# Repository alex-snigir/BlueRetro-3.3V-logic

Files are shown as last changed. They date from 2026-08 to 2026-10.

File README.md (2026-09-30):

*Read this in other languages: [English](README_EN.md)*

# BlueRetro + Murmulator: Bluetooth-джойстики для эмулятора ретро компьютеров на перфборде

Подключение Bluetooth-геймпадов (Xbox One, PS/Switch и других HID-устройств) к эмулятору ретро компьютеров [Murmulator](https://murmulator.ru/howto) (RP2040) в качестве двух NES/Dendy-совместимых джойстиков через самодельный адаптер [BlueRetro](https://github.com/darthcloud/BlueRetro) (ESP32), выступающий мостом.

BlueRetro эмулирует на выходе стандартный протокол сдвигового регистра NES/Dendy (CLOCK/LATCH/DATA) и подключается напрямую к джойстик-портам DE-9 Мурмулятора — проводные NES-контроллеры в проекте не используются.

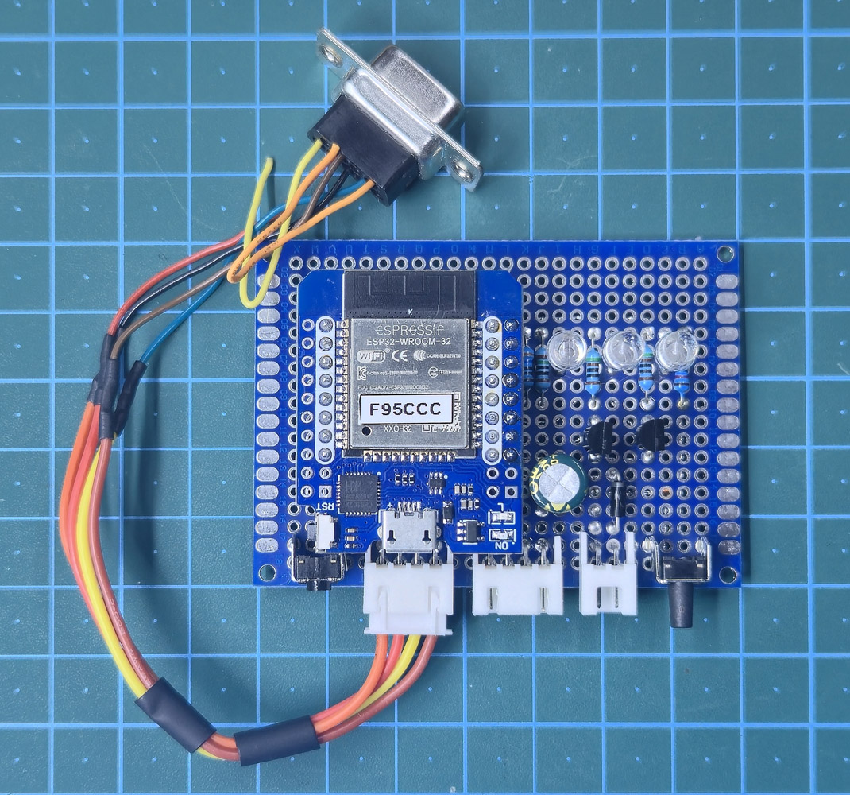
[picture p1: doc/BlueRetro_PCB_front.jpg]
BlueRetro PCB


## Железо

- **Хост:** Murmulator (RP2040, сборка на перфборде) — VGA, PS/2-клавиатура, аудио, джойстик-порты.
- **Адаптер:** самодельный BlueRetro на ESP32 D1 mini (MH-ET LIVE, CH9102), прошивка по спецификации HW1, собственная KiCad-схема с глобальным и портовыми светодиодами статуса, входной защитой питания и вынесенной кнопкой BOOT/IO0.
- **Кабели:** JST XH 4-pin (BlueRetro) → DE-9 (Murmulator), распиновка и разводка описаны в project summary.
- **Схемы:** KiCad-проект платы BlueRetro — [`schematics/BlueRetro3V3/`](schematics/BlueRetro3V3/) (готовый PDF: [`BlueRetro3V3.pdf`](schematics/BlueRetro3V3/BlueRetro3V3.pdf)).

## Документация

| Файл | Описание |
|---|---|
| [`doc/blueretro-murmulator-project-summary.md`](doc/blueretro-murmulator-project-summary.md) / [`_EN`](doc/blueretro-murmulator-project-summary_EN.md) | Полное техническое описание: выбор платы, распиновка, питание, LED-индикация, прошивка, проверка осциллографом |
| [`doc/blueretro-murmulator-user-guide.md`](doc/blueretro-murmulator-user-guide.md) / [`_EN`](doc/blueretro-murmulator-user-guide_EN.md) | Повседневное использование: пейринг и отключение Bluetooth-геймпадов |
| [`doc/blueretro-xbox-one-nes-oscillograms.pdf`](doc/blueretro-xbox-one-nes-oscillograms.pdf) / [`_EN`](doc/blueretro-xbox-one-nes-oscillograms_EN.pdf) | Осциллограммы проверки: геймпад Xbox One как NES-джойстик — LATCH, «ничего не нажато» и поочерёдное нажатие всех 8 кнопок (исходники: [`.docx`](doc/blueretro-xbox-one-nes-oscillograms.docx) / [`_EN.docx`](doc/blueretro-xbox-one-nes-oscillograms_EN.docx); снимки — [`doc/XBox One as NES Joystick Debugging/`](<doc/XBox One as NES Joystick Debugging/>)) |
| [`murmulator-vga-project-summary.md`](https://github.com/alex-snigir/Murmulator-RP2040-Black-Perfboard-VGA/blob/master/doc/murmulator-vga-project-summary.md) / [`_EN`](https://github.com/alex-snigir/Murmulator-RP2040-Black-Perfboard-VGA/blob/master/doc/murmulator-vga-project-summary_EN.md) | Базовая сборка Мурмулятора на перфборде (хост-платформа) — отдельный репозиторий |

## Статус

Железо собрано и проверено: пейринг, работа двух портов и протокол CLOCK/LATCH/DATA подтверждены осциллографом на реальных нажатиях кнопок Xbox One.

## Благодарности

Проект основан на [BlueRetro](https://github.com/darthcloud/BlueRetro) авторства darthcloud (CERN-OHL-P-2.0 / Apache-2.0) и платформе [Murmulator](https://murmulator.ru/howto).

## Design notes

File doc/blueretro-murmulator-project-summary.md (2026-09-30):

# Project Summary: BlueRetro — подключение 2х NES/Dendy джойстиков к Murmulator

**Версия документа:** 1.0 · **Дата:** 2026-09-30

## Связанные документы
- **Базовый проект**: [BlueRetro](https://github.com/darthcloud/BlueRetro) (darthcloud) — open-source адаптер Bluetooth-контроллеров для ретро-консолей на базе ESP32, на чьих прошивке и HW1-спецификации построена данная сборка. Документация: [BlueRetro Wiki](https://github.com/darthcloud/BlueRetro/wiki).
- **Связанный проект-хост**: `murmulator-vga-project-summary.md` (проект "Murmulator") — одна из сборок Мурмулятора (RP2040 Black Perfboard: VGA, Joystick, AudioOut, AudioIn), используемая для текущей интеграции BlueRetro; не единственная возможная целевая платформа.

## Цель проекта
Подключить Bluetooth-геймпады (Xbox One, PS/Switch и др. HID-устройства) к Murmulator (устройство на базе RP2040) в качестве двух NES/Dendy-совместимых джойстиков через устройство BlueRetro, которое эмулирует стандартный протокол сдвигового регистра NES/Dendy (9-pin, CLOCK/LATCH/DATA) на выходе, выступая мостом между Bluetooth-контроллерами и Мурмулятором. Физические проводные NES/Dendy-джойстики в проекте не используются.

## Контекст компонентов

### Murmulator (эмулятор ретро компьютеров)
- Основа: RP2040 black clone, самодельная плата (Perfboard).
- Функциональность (согласно `murmulator-vga-project-summary.md`): вывод VGA, поддержка джойстика, аудиовыход, аудиовход.
- Данный проект расширяет базовую платформу поддержкой двух NES/Dendy джойстиков через BlueRetro.

### BlueRetro (адаптер)
- Открытое железо и прошивка на базе ESP32, лицензии CERN-OHL-P-2.0 (hardware) и Apache-2.0 (software).
- Изначально спроектирован как переходник "Bluetooth-контроллер → консоль": поддерживает Wii, Switch, PS3, PS4, PS5, Xbox One, Xbox Series X|S и generic HID Bluetooth (BR/EDR и LE) устройства, а на выходе эмулирует протоколы множества консолей, включая NES.
- Для NES/Famicom: может эмулировать стандартный 8-кнопочный NES-контроллер (GamePad), мультитап Four Score на 4 контроллера (Dual), японский 4P-адаптер (Alt), клавиатуру Famicom или Hori Trackball (мышь).
- В данном проекте используется **штатный** сценарий работы BlueRetro: адаптер физически подключается к джойстик-порту хоста (в данном случае — к Murmulator) и эмулирует на выходе стандартный NES/Dendy-протокол сдвигового регистра, а на вход принимает Bluetooth/HID-геймпады (Xbox One и др.). Проводные NES/Dendy-джойстики на входе BlueRetro не используются.
- Схемы распайки NES-кабелей и особенности PAL-подтяжек описаны в [BlueRetro Cables Build Instructions](https://github.com/darthcloud/BlueRetro/wiki/BlueRetro-Cables-Build-Instructions): для PAL-систем требуется добавление подтягивающих резисторов 3.6К к NES 5V (pin 5) на пады IO18, IO5 и IO32.
- Общая сборка описана в [BlueRetro DIY Build Instructions](https://github.com/darthcloud/BlueRetro/wiki/BlueRetro-DIY-Build-Instructions): прошивка BlueRetro на ESP32, сборка кабеля-адаптера под целевую систему, опциональная настройка через Web Bluetooth.
- **В данном проекте**: на плате BlueRetro распаяны 2 разъёма JST XH 1x04 (J1/J2), к которым подключены самодельные кабели-переходники JST XH 4-pin male → DE-9 female, оканчивающиеся разъёмами DE-9 female — они подключаются напрямую к джойстик-портам DE-9 male на Murmulator.
- Настройка выполняется через BLE Web Config (Desktop/Android Chrome), позволяющий гибко маппить кнопки, настраивать turbo-режимы и т.д.

## Выбор Dev Board (ESP32)

**Итоговое решение: ESP32 D1 mini MH-ET LIVE (CH9102).**

**Рассмотренные альтернативы:**

| Плата | Вердикт |
|---|---|
| ESP32-WROOM-32 DevKit, **30 pin**, CP2102 | Отпала — на этом форм-факторе физически **не выведен пин GPIO0**, необходимый для BOOT/pairing и всех режимов сброса BlueRetro (проверено по пинаутам конкретных плат в наличии) |
| ESP32-WROOM-32 DevKit, **38 pin**, CP2102 | Технически пригодна и соответствует официальной рекомендации автора BlueRetro (см. ниже) — GPIO0 выведен. Не выбрана, так как потребовала бы переделки уже готовой и проверенной в железе KiCad-схемы (другой footprint, другие габариты платы); на текущем этапе (PCB близка к финализации) это признано нецелесообразным |
| ESP32 D1 mini MH-ET LIVE, CH9102 (выбрана) | Схема и распиновка уже спроектированы и проверены в железе под эту плату; конфликтов бортовой периферии с используемыми пинами (IO2, IO4, IO5, IO17, IO18, IO19, IO22, IO32, IO0) не выявлено |

**On-board LED платы:** на ESP32 D1 mini MH-ET LIVE штатный (built-in) LED подключён к **GPIO2** и загорается, когда GPIO2 находится в состоянии **HIGH**. В данной сборке GPIO2 занят под индикацию порта 1 (см. раздел «LED-подсистема индикации» ниже) — при HIGH на IO2 (LED порта 1 через MOSFET Q1 горит) штатный on-board LED платы будет параллельно повторять это состояние (гореть одновременно с внешним LED порта 1). Это не создаёт электрического конфликта (GPIO2 остаётся выходом, on-board LED — лишь дополнительная, немного избыточная индикация того же сигнала), но стоит иметь в виду при сборке в корпусе — штатный LED платы может быть виден снаружи, если не закрыт.

**Официальная позиция сообщества BlueRetro:** автор проекта (darthcloud) в официальной документации указывает конкретную рекомендуемую плату — **ESP32-DevKitC-32E/D с модулем ESP-WROOM-32** (38-pin форм-фактор). Причины:
- На дешёвых клонах бывают конфликты бортовой периферии с пинами, которые использует BlueRetro (задокументированный случай — светодиод на IO5 на плате Wemos Lolin32, из-за которого прошивка зависает в цикле сброса).
- Важно, чтобы внутри стоял модуль именно **WROOM** (не WROVER) — у WROVER на 2 GPIO меньше из-за встроенной PSRAM.
- Сторонние производители готовых китов для BlueRetro (например, RetroRosetta) придерживаются той же рекомендации — использовать только официальные DevKit-платы.

**Почему аргумент «штатная кнопка BOOT» не сыграл роли:** кнопки BOOT и RESET в данном проекте в любом случае выносятся на корпус устройства (3D-печатной коробки) отдельными проводами — поэтому наличие или отсутствие штатной кнопки BOOT на самой плате не имеет значения при выборе.

**Известный компромисс выбранной платы — нагрев регулятора:** встроенный линейный стабилизатор **AMS1117** (5V→3.3V) на D1 mini греется в работе до ~54°C. Это не уникальная проблема D1 mini — тот же AMS1117 стоит и на WROOM-32 DevKit платах, но на маленькой плате D1 mini меньше меди PCB для отвода тепла. 54°C не критично для самого регулятора, но близко к температуре размягчения PLA (используется в 3D-печатном корпусе) — при плотной компоновке возможна деформация пластика при долгой работе без вентиляции.

**Риск принят** — сборка эксплуатируется как есть. Если нагрев всё же станет проблемой, возможны два варианта:
1. Вентиляционное отверстие в корпусе над регулятором.
2. Обход/выпайка встроенного AMS1117 с подачей готовых 3.3V от отдельного внешнего DC-DC регулятора (по аналогии с доработкой SD-модуля в `murmulator-vga-project-summary.md`, раздел 2).

## Аппаратная сборка BlueRetro
- Используется DIY-сборка на базе **ESP32 D1 mini (MH-ET LIVE, USB-serial чип CH9102)** — самодельная, не готовая плата BlueRetroHW.
- **⚠️ Кнопка BOOT/IO0 отсутствует на плате D1 mini.** В отличие от полноразмерного ESP32 DevKitC, на D1 mini физически разведена только кнопка **RST/EN** (сброс модуля) — отдельной кнопки BOOT нет. Функции BlueRetro (пейринг, сброс конфигурации, factory reset — см. раздел "Кнопка BOOT (IO0)" ниже) завязаны именно на IO0, поэтому нужно **допаять отдельную кнопку между IO0 и GND**.
  - Внешний pull-up резистор в теории не обязателен — ESP32 включает внутренний pull-up на IO0 (strapping-пин) аппаратно при старте. Кнопка просто замыкает IO0 на GND при нажатии.
  - **На практике встроенный pull-up на конкретном модуле оказался нестабильным**, поэтому в финальной KiCad-схеме внешний резистор **R1 = 10 кОм (от IO0 к +3.3V) впаян безусловно**, как штатный компонент, а не как опциональный запасной вариант.

### Кнопка BOOT (IO0) — функции BlueRetro
⚠️ Тайминги и действия ниже соответствуют используемой версии прошивки (`v25.04_hw1`, см. раздел "Прошивка firmware"). В других версиях BlueRetro длительности удержания и результат могут отличаться — сверяться с BlueRetro Wiki для конкретной установленной версии.
- Короткое нажатие (< 3 сек) — обычный сброс системы.
- Удержание 3–6 сек (LED IO17 мигает медленно) — запуск режима пейринга (pairing mode).
- Удержание 6–10 сек (LED IO17 мигает быстро) — сброс к дефолтной конфигурации.
- Удержание > 30 сек — полный factory reset ESP32 (заводская прошивка + сброс настроек).
- В режиме пейринга короткое нажатие останавливает пейринг / отключает все Bluetooth-устройства.

## Распиновка (согласовано с murmulator-vga-project-summary.md)

**Топология:** ESP32 (BlueRetro) → разъёмы J1/J2 (JST XH 1x04, на плате BlueRetro) → кабель-переходник (JST XH 4-pin male → DE-9 female) → разъёмы J6/J7 (DE-9 male, на плате Murmulator) → GPIO Pico.

| Сигнал | Нога ESP32 (BlueRetro) | JST XH J1 (P1) | JST XH J2 (P2) | DE-9 Murmulator J6 (P1) | DE-9 Murmulator J7 (P2) | GPIO Pico |
|---|---|---|---|---|---|---|
| LATCH (общий) | IO32 | pin 1 | pin 1 | pin 3 | pin 3 | GP15 |
| CLOCK порт 1 | IO5 | pin 2 | — | pin 4 | — | GP14 |
| CLOCK порт 2 | IO18 | — | pin 2 | — | pin 4 | GP14* |
| DATA порт 1 | IO19 | pin 3 | — | pin 2 | — | GP16 |
| DATA порт 2 | IO22 | — | pin 3 | — | pin 2 | GP17 |
| GND | GND ESP32 | pin 4 | pin 4 | pin 8 | pin 8 | GND |
| VCC (+5V) | — | не разведено | не разведено | pin 6 | pin 6 | **не подключать** |

**Распайка кабеля-переходника (JST XH 4-pin male → DE-9 female), одинаковая для обоих портов:**

| JST XH pin | Сигнал | DE-9 pin |
|---|---|---|
| 1 | LATCH | 3 |
| 2 | CLOCK | 4 |
| 3 | DATA | 2 |
| 4 | GND | 8 |

\* **CLOCK и LATCH генерирует RP2040 (Murmulator выступает хостом/консолью)** — это один физический сигнал GP14/GP15, разведённый на оба разъёма J6 и J7 одновременно. IO5 и IO18 на ESP32 (BlueRetro эмулирует джойстик/слейв) — это два **входа**, слушающие этот сигнал, а не два независимых генератора. Электрического конфликта (bus contention) при объединении не возникает, так как RP2040 — единственный активный драйвер линии. Прошивка BlueRetro внутренне обрабатывает IO5/IO18 как два независимых входа CLOCK (на случай консолей, где CLOCK P1/P2 физически не объединены) — при подключении к Murmulator оба входа неизбежно получают один и тот же физический сигнал.

VCC (pin 6, DE-9 Murmulator) сознательно не подключается: ESP32 внутри BlueRetro работает на 3.3V-логике, сигнальные линии заводятся на GPIO Pico напрямую без level-shifter'ов; питание BlueRetro организовано отдельно, через собственный разъём J3 платы (см. раздел "Питание BlueRetro"). На разъёмах JST XH J1/J2 (порты джойстика на стороне BlueRetro) линии +5V нет вообще — там только 4 сигнала (LATCH/CLOCK/DATA/GND).

## Питание BlueRetro (ESP32-модуль)
- ESP32 D1 mini (со встроенным стабилизатором AMS1117, 5V→3.3V) может питаться двумя способами — по отдельности или одновременно:
  1. **Через J3 платы BlueRetro** — от разъёма J2 Мурмулятора (отвод «сырого» +5V внешнего PSU, до диода D1 Мурмулятора, см. `murmulator-vga-project-summary.md`, раздел 10) → диод Шоттки D1 = 1N5819 на плате BlueRetro → пин 5V D1 mini. Из-за падения на диоде на пин 5V D1 mini приходит не 5V, а меньше (~4.5–4.7V).
  2. **Через micro-USB на D1 mini** (от ПК или USB-адаптера).
- **Одновременное подключение J3 и micro-USB допустимо.** На D1 mini защитного диода нет: пин 5V напрямую соединён с VBUS micro-USB и входом стабилизатора 3.3V. Развязку обеспечивает только диод Шоттки D1 = 1N5819 на входе J3: он не пропускает ток от USB в PSU Мурмулятора, а напряжение после него ниже 5V, поэтому при одновременном подключении нагрузку берёт на себя USB. Условие безопасности — напряжение PSU минус падение на D1 (при малом токе ~0.15–0.25V) должно оставаться ниже напряжения USB-порта; иначе PSU будет подпитывать VBUS компьютера обратным током. При PSU ~5.0V условие выполняется с запасом.
- **⚠️ Ограничение при питании только через J3:** BlueRetro и оба джойстика работают только при подключённом внешнем PSU Мурмулятора. На YD-RP2040 нет доступного USB VBUS до объединяющего диода BAT54C, поэтому от USB Мурмулятора BlueRetro не запитать. При питании через micro-USB D1 mini это ограничение не действует.
- **Измерено (мультиметр):** пиковое потребление тока ESP32 по шине 5V при активном BT-радио — **~155 мА**. Питание через J2 (на плате Мурмулятора) → J3 (на плате BlueRetro) идёт в обход диода BAT54C и узла Vout Мурмулятора (см. `murmulator-vga-project-summary.md`), поэтому эта нагрузка не делит бюджет тока с PS/2-клавиатурой и не ограничена номиналом BAT54C (~150–300 мА на плечо) — запас по току достаточен.
- GND сигнальных линий (LATCH/CLOCK/DATA) общий с Мурмулятором при любом варианте питания — через разъёмы J1/J2 (JST XH) и кабели-переходники к J6/J7.

## Входная защита питания, RESET и развязка

**Разъём внешнего 5V (J3) и защитный диод D1:**
- **J3** — отдельный 2-контактный разъём («External 5V Power Connector»), через который на плату заводится питание от шины 5V внешнего PSU (см. раздел «Питание BlueRetro» выше).
- **D1 = 1N5819** (Schottky, 40V/1A) включён между J3 и шиной +5V: анод — со стороны J3, катод — со стороны +5V. Функция — защита от переполюсовки / развязка входа (аналог diode-OR BAT54C на самом Мурмуляторе, см. `murmulator-vga-project-summary.md`, раздел 10).

**Кнопка RESET (SW2):**
- Отдельная кнопка **SW2**, замыкающая **RST** ESP32-модуля на GND — штатный аппаратный сброс модуля, независимый от логики BOOT/IO0 (см. таблицу функций кнопки BOOT выше).

**Развязывающие конденсаторы (bulk + bypass на обеих шинах питания):**

| Шина | Bulk (электролит) | Bypass (керамика) |
|---|---|---|
| +5V (вход, после J3/D1) | C5 = 470 мкФ | C6 = 100 нФ |
| +3V3 (выход стабилизатора ESP32-модуля) | C8 = 220 мкФ | C7 = 100 нФ |

Оба конденсатора на каждой шине включены параллельно, между шиной и GND — классическая пара «объёмная фильтрация + высокочастотная развязка».

---

## LED-подсистема индикации (финальная, проверено в железе)

По документации BlueRetro Wiki (разделы про LED usage) индикация состоит из двух типов светодиодов: **один global-status LED на IO17** и до **четырёх port-status LED** (по одному на порт). В данной сборке реализованы global-LED + два port-LED (на оба порта джойстика, P1/P2).

**Примечание про IO17 vs встроенный LED платы:** на некоторых ESP32 DevKitC/D1 mini платах штатный (built-in) LED сидит на IO2, но в прошивке BlueRetro этот вывод занят под цепь авто-программирования — поэтому для индикации нужен отдельный внешний светодиод именно на IO17, не полагаясь на встроенный power/status LED платы.

**Распределение выводов ESP32:**

| ESP32 IO | Функция | LED | Способ подключения |
|---|---|---|---|
| IO17 | Global status (статус адаптера / ошибка / пейринг) | D3, синий | двухрезисторная pull-up схема (прямо) |
| IO2 | Port 1 status | D4, зелёный | через MOSFET Q1 (2N7000) |
| IO4 | Port 2 status | D5, зелёный | через MOSFET Q2 (2N7000) |

IO2/IO4/IO17 — все strapping-пины ESP32. Через MOSFET заведены только port-LED D4 (IO2) и D5 (IO4) — требование данной аппаратной ревизии BlueRetro, чтобы нагрузка LED не мешала загрузке; IO17 (D3) использует отдельную pull-up-схему без MOSFET (см. выше). Порты 3/4 (при расширении) — это IO12/IO15, но в режиме PlayStation они переназначаются под индикацию аналогового режима; для NES-режима неактуально.

**Логика поведения (подтверждена реальным тестом):**
- Питание, без ошибки → авто-пейринг: global-LED (IO17) **пульсирует** + LED первого доступного порта (IO2) **пульсирует**; второй порт (IO4) выключен.
- 1-й геймпад подключён → IO17 гаснет, порт 1 (IO2) **solid**.
- 2-й геймпад подключён → порт 2 (IO4) **solid**, IO17 остаётся выключенным.
- Отключение геймпада → его port-LED гаснет; при освобождении порта адаптер возвращается в пейринг (global + первый свободный порт снова пульсируют).

### Схема global-status LED IO17 (двухрезисторный вариант)

⚠️ Отличается от официальной однорезисторной схемы вики (R36 ≈ 65 Ом–1 кОм, LED прямо между узлом и GND). В данной сборке — **два резистора**, что улучшает поведение:

```
+3V3 --[R2 360R]--+-- IO17 (U1 pin 25)
                  |
                  +--[R3 150R]--[D3 anode >|< cathode]-- GND
```
IO17 подключён к узлу между R2 и R3 (со стороны анода LED), а не к GND-стороне.

**Роли резисторов:**
- **R2 = 360R** — pull-up 3.3V→IO17. Обеспечивает fail-safe (при high-Z LED тускло горит) и определяет паразитный сток в GPIO при LOW. На рабочую яркость **не влияет**.
- **R3 = 150R** — последовательный токоограничивающий резистор LED. Задаёт яркость в HIGH-PWM (пульсация/solid). Ограничивает ток при активном push-pull HIGH.

**Логика (fail-safe по умолчанию):**
- IO17 по умолчанию (не сконфигурирован, high-Z/вход) → R2 дотягивает узел к 3.3V → **LED тускло горит сам по себе**, без команды прошивки.
- Прошивка после успешного старта **явно переводит IO17 в выход LOW** → узел к 0V → **LED гаснет**.
- Смысл инверсии: если прошивка не загрузилась (краш до инициализации) — IO17 остаётся high-Z, LED **продолжает гореть** = индикация ошибки. В классической схеме такой сбой был бы неотличим от штатного «выключено».
- Пульсация/статус: прошивка через LEDC переключает IO17 в ШИМ (~200 мкс, скважность 0–20 %), создавая «дыхание». Подтверждено осциллографом.

### Схема port-status LED (IO2/IO4, через MOSFET)

```
+3V3 --[D4/D5 anode >|< cathode]--[R4/R5 510R]-- drain Q1/Q2
                                                 gate  -- IO2/IO4
                                                 source-- GND
```
При HIGH на IO2/IO4 → MOSFET открыт → LED горит. При закрытом MOSFET ток не течёт вообще — здесь **нет** проблемы «стока в GPIO» (в отличие от IO17), поэтому port-LED можно гонять на рабочем токе без оглядки на нагрузку GPIO.

### Итоговые номиналы и токи (измеренные Vf)

Vf измерены мультиметром-вольтметром на LED через 510R к 3.3V (высокий входной импеданс → честная рабочая точка): **синий Vf = 2.6 В @ ~1.4 мА, зелёный Vf = 2.4 В @ ~1.76 мА.**

| LED | Цвет | Vf | Цепь | Ток | Состояние |
|---|---|---|---|---|---|
| D3 (IO17) | синий | 2.6 В | R3 = 150R | ~4.0–4.5 мА | HIGH-PWM (пульсация/статус) |
| D3 (IO17) | синий | 2.6 В | R2 = 360R | ~9.2 мА | LOW — сток в GPIO (зависит только от R2) |
| D3 (IO17) | синий | 2.6 В | R2+R3 = 510R | ~1.37 мА | high-Z — fail-safe (ошибка старта) |
| D4/D5 (порты) | зелёный | 2.4 В | R4/R5 = 510R | ~1.76 мА | solid (порт подключён) |

**Баланс яркости:** port-LED зелёные работают при меньшем токе (~1.76 мА), чем синий статусный (~4.5 мА), но за счёт максимальной чувствительности глаза к зелёному (~555 нм) и слабой — к синему, визуально они сопоставимы. R4/R5 = 510R — при более низком номинале (150R) зелёный станет ярче синего, нарушая баланс.

**Визуальная проверка:** при одновременном свечении синего (IO17) и зелёного (порт 1) во время пейринга яркости сопоставимы. При необходимости R4/R5 можно снизить до ~330R (~2.7 мА) — но не ниже.

**Запас по напряжению (headroom):** у синего LED запас невелик (3.3 − 2.6 = 0.7 В), поэтому яркость чувствительна к просадкам 3.3V-шины — при 3.2 В ток в HIGH падает до ~4 мА, что остаётся в норме.

## Проверка сигналов осциллографом (подтверждено)

📄 Полный набор осциллограмм (LATCH, «ничего не нажато» и поочерёдное нажатие каждой из 8 кнопок геймпада Xbox One) с описанием подключения и настроек осциллографа — в документе **`blueretro-xbox-one-nes-oscillograms.docx`** (исходные снимки — в папке `XBox One as NES Joystick Debugging`).

**CLOCK (GP14 → IO5/IO18):** период 80 мкс (≈12.5 кГц), скважность 50% (HIGH = LOW = 40 мкс), амплитуда 0V ↔ 3.3V, чистые фронты.

**LATCH (GP15 → IO32):** период повторения 1200 мкс (≈833 Гц), длительность импульса 40 мкс, амплитуда 0V ↔ 3.3V.

- Длительность импульса LATCH (40 мкс) равна одной фазе CLOCK — типично для фиксации параллельно загруженного состояния кнопок перед серией сдвиговых тактов.
- За один период LATCH укладывается 1200 / 80 = 15 полных тактов CLOCK — достаточно для вычитывания 8-битного регистра с запасом.
- Частота опроса ~833 Гц (подтверждено осциллографом) — заметно выше классической NES/Famicom (~60 Гц, синхронно с кадром).
- Амплитуда 0V/3.3V на обеих линиях подтверждает штатную работу топологии «один драйвер (Pico) — приёмники (ESP32)», без конфликта шины.

**DATA (IO19/IO22 → GP16/GP17):** при нажатии кнопок на геймпаде Xbox One (A, X, View, Menu, D-pad Up/Down/Left/Right на линии DATA наблюдается импульс **LOW (~0V) длительностью 80 мкс** — ровно один период CLOCK.
**Первая кнопка отдаётся без тактового импульса:** как только Мурмулятор подаёт сигнал LATCH (защёлка), микросхема мгновенно выставляет значение кнопки A на линию DATA (это 0-й бит). Следующие кнопки (X, View, Menu и т.д.) выдаются по очереди на каждый следующий тактовый импульс CLOCK.

- Протокол использует **инверсную логику**: LOW = кнопка нажата, HIGH (3.3V) = кнопка отпущена — штатное соглашение для NES/Dendy-совместимого сдвигового регистра.
- Длительность импульса (80 мкс) точно совпадает с периодом CLOCK — подтверждает, что каждый бит выставляется на DATA ровно на один такт сдвига, синхронно и без фазового сдвига.
- Соответствие «нажатая физическая кнопка Xbox → LOW-импульс в ожидаемом такте» подтверждает корректный маппинг BlueRetro (Xbox One HID → NES-биты) и правильное считывание Мурмулятором на стороне RP2040.

**Порядок бит DATA в сдвиговом регистре NES и соответствие Xbox One (подтверждено):**

| Такт | Бит | Кнопка Xbox One | Роль (NES-бит) |
|---|---|---|---|
| 1 | 0 | A | A |
| 2 | 1 | X | B |
| 3 | 2 | View | Select |
| 4 | 3 | Menu | Start |
| 5 | 4 | D-pad Up | Up |
| 6 | 5 | D-pad Down | Down |
| 7 | 6 | D-pad Left | Left |
| 8 | 7 | D-pad Right | Right |

Порядок бит **A, B, Select, Start, Up, Down, Left, Right** — это стандартный, канонический порядок выдачи бит в оригинальном NES-контроллере (тот же порядок, в котором консоль NES исторически считывала регистр 4021). Совпадение подтверждает, что BlueRetro в режиме `GamePad`/NES эмулирует классический протокол один в один, без изменения порядка бит, а Мурмулятор читает их в этом же порядке.

Проверка подтверждает как электрическую целостность сигналов CLOCK/LATCH, так и корректное фазовое согласование DATA относительно CLOCK — данные снимаются в правильный момент такта.

## Прошивка firmware (проверено, рабочий вариант)

**Версия прошивки:** `v25.04_hw1.zip` (архив с [GitHub Releases](https://github.com/darthcloud/BlueRetro/releases)) — используется HW1-спецификация (см. раздел "Аппаратная сборка BlueRetro").

**Файлы из архива:**
- `bootloader.bin`
- `partition-table.bin`
- `ota_data_initial.bin`
- `BlueRetro_hw1_nes.bin` (система-специфичная прошивка под NES)

**Команда прошивки (Windows, через PlatformIO Core):**

```
pio pkg exec -- esptool.py -p COM6 -b 460800 --before default_reset --after hard_reset --chip esp32 write_flash --flash_mode dio --flash_size detect --flash_freq 40m 0x1000 bootloader.bin 0x8000 partition-table.bin 0xD000 ota_data_initial.bin 0x10000 BlueRetro_hw1_nes.bin
```

Порт `COM6` — под конкретный экземпляр платы, уточнять в Диспетчере устройств Windows при каждой прошивке.

**Примечание:** при прямом вызове `python esptool.py ...` (не через `pio pkg exec`) может не хватать зависимостей esptool, так как системный Python не видит окружение, куда PlatformIO их устанавливал — команда через `pio pkg exec --` обходит эту проблему, используя корректное окружение автоматически.

**Full flash erase:**
```
pio pkg exec -- esptool.py -p COM6 --chip esp32 erase_flash
```

**Serial Monitor Debug:**
```
pio device monitor -p COM6 -b 921600
```

**Параметры SecureCRT Serial Monitor:**
```
Connection:
  Serial:
    Port: COM6
    Baud rate: 921600
Terminal:
  Emulation:
    Modes:
      [v] New line mode
```

### Первичная настройка после прошивки (BlueRetro Web Configurator)

После прошивки может потребоваться настройка через Web Config — в данном случае сборка заработала на дефолтных настройках, ниже приведена конфигурация для проверки/справки.

**Адрес:** [https://blueretro.io/](https://blueretro.io/)

⚠️ Конфигурация BlueRetro доступна только когда **ни один контроллер не подключён** — сделано специально, чтобы не отбирать эфирное время у геймпадов во время игры.

**Порядок действий:**
1. Открыть **"BlueRetro Advance config"**.
2. Нажать **[Connect BlueRetro]** — при необходимости повторять клик, пока не установится соединение.
3. Откроется всплывающее окно со списком Bluetooth-устройств — выбрать устройство BlueRetro и нажать **[Pair]**.
4. **Global Config:**
   - System: `NES`
   - Multitap: `None`
5. **Output Config:**
   - Output 1 → Mode: `GamePad`, Accessories: `None`
   - Output 2 → Mode: `GamePad`, Accessories: `None`
6. **[Save]**

## Пейринг и отключение геймпадов

Практические инструкции по подключению (pairing) и отключению/сбросу пары (unpairing) Bluetooth-геймпадов — вынесены в отдельный документ **`blueretro-murmulator-user-guide.md`**.

## Открытые вопросы (требуют уточнения/проверки)
*(на данный момент нет)*

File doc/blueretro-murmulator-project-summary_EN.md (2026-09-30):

# Project Summary: BlueRetro — connecting 2 NES/Dendy joysticks to Murmulator

**Document version:** 1.0 · **Date:** 2026-09-30

## Related documents
- **Base project**: [BlueRetro](https://github.com/darthcloud/BlueRetro) (darthcloud) — an open-source Bluetooth controller adapter for retro consoles based on ESP32, whose firmware and HW1 specification this build is based on. Documentation: [BlueRetro Wiki](https://github.com/darthcloud/BlueRetro/wiki).
- **Related host project**: `murmulator-vga-project-summary.md` (the "Murmulator" project) — one of the Murmulator builds (RP2040 Black Perfboard: VGA, Joystick, AudioOut, AudioIn) used for the current BlueRetro integration; not the only possible target platform.

## Project goal
Connect Bluetooth gamepads (Xbox One, PS/Switch, and other HID devices) to the Murmulator (an RP2040-based device) as two NES/Dendy-compatible joysticks via the BlueRetro device, which emulates the standard NES/Dendy shift-register protocol (9-pin, CLOCK/LATCH/DATA) on its output, acting as a bridge between Bluetooth controllers and the Murmulator. Physical wired NES/Dendy joysticks are not used in this project.

## Component context

### Murmulator (retro computer emulator)
- Base: RP2040 black clone, a homemade board (perfboard).
- Functionality (per `murmulator-vga-project-summary.md`): VGA output, joystick support, audio output, audio input.
- This project extends the base platform with support for two NES/Dendy joysticks via BlueRetro.

### BlueRetro (adapter)
- Open hardware and firmware based on ESP32, licensed under CERN-OHL-P-2.0 (hardware) and Apache-2.0 (software).
- Originally designed as a "Bluetooth controller → console" adapter: supports Wii, Switch, PS3, PS4, PS5, Xbox One, Xbox Series X|S, and generic HID Bluetooth (BR/EDR and LE) devices, and emulates the protocols of many consoles on the output, including NES.
- For NES/Famicom: can emulate a standard 8-button NES controller (GamePad), the Four Score multitap for 4 controllers (Dual), the Japanese 4P adapter (Alt), the Famicom keyboard, or the Hori Trackball (mouse).
- This project uses the **standard** BlueRetro operating scenario: the adapter is physically connected to the joystick port of the host (in this case, the Murmulator) and emulates the standard NES/Dendy shift-register protocol on its output, while accepting Bluetooth/HID gamepads (Xbox One, etc.) as input. Wired NES/Dendy joysticks are not used on the BlueRetro input.
- NES cable wiring diagrams and PAL pull-up specifics are described in [BlueRetro Cables Build Instructions](https://github.com/darthcloud/BlueRetro/wiki/BlueRetro-Cables-Build-Instructions): for PAL systems, 3.6K pull-up resistors to NES 5V (pin 5) need to be added to pads IO18, IO5, and IO32.
- The overall build is described in [BlueRetro DIY Build Instructions](https://github.com/darthcloud/BlueRetro/wiki/BlueRetro-DIY-Build-Instructions): flashing BlueRetro firmware onto the ESP32, building the adapter cable for the target system, optional configuration via Web Bluetooth.
- **In this project**: the BlueRetro board has 2 JST XH 1x04 connectors (J1/J2) soldered on, to which homemade adapter cables (JST XH 4-pin male → DE-9 female) are connected, terminating in DE-9 female connectors — these plug directly into the DE-9 male joystick ports on the Murmulator.
- Configuration is done via BLE Web Config (Desktop/Android Chrome), which allows flexible button mapping, turbo mode configuration, etc.

## Dev board (ESP32) selection

**Final decision: ESP32 D1 mini MH-ET LIVE (CH9102).**

**Alternatives considered:**

| Board | Verdict |
|---|---|
| ESP32-WROOM-32 DevKit, **30 pin**, CP2102 | Rejected — on this form factor the **GPIO0 pin is physically not broken out**, and it is required for BOOT/pairing and all BlueRetro reset modes (checked against the pinouts of the specific boards on hand) |
| ESP32-WROOM-32 DevKit, **38 pin**, CP2102 | Technically suitable and matches the official recommendation of the BlueRetro author (see below) — GPIO0 is broken out. Not chosen because it would require reworking the already finished and hardware-verified KiCad schematic (different footprint, different board dimensions); at the current stage (PCB close to finalization) this was deemed impractical |
| ESP32 D1 mini MH-ET LIVE, CH9102 (chosen) | The schematic and pinout are already designed and hardware-verified for this board; no conflicts between on-board peripherals and the pins used (IO2, IO4, IO5, IO17, IO18, IO19, IO22, IO32, IO0) were found |

**Board on-board LED:** on the ESP32 D1 mini MH-ET LIVE the built-in LED is connected to **GPIO2** and lights up when GPIO2 is **HIGH**. In this build GPIO2 is used for port 1 indication (see the "LED indication subsystem" section below) — when IO2 is HIGH (port 1 LED lit via MOSFET Q1), the board's built-in LED mirrors this state (lights up together with the external port 1 LED). This creates no electrical conflict (GPIO2 remains an output; the on-board LED is just an additional, somewhat redundant indication of the same signal), but keep it in mind when assembling into the enclosure — the board's built-in LED may be visible from outside if not covered.

**Official position of the BlueRetro community:** the project author (darthcloud) names a specific recommended board in the official documentation — **ESP32-DevKitC-32E/D with the ESP-WROOM-32 module** (38-pin form factor). Reasons:
- Cheap clones sometimes have on-board peripherals that conflict with pins used by BlueRetro (a documented case — an LED on IO5 on the Wemos Lolin32 board, which makes the firmware hang in a reset loop).
- The module inside must be a **WROOM** (not WROVER) — WROVER has 2 fewer GPIOs because of its built-in PSRAM.
- Third-party makers of ready-made BlueRetro kits (e.g., RetroRosetta) follow the same recommendation — use only official DevKit boards.

**Why the "built-in BOOT button" argument played no role:** in this project the BOOT and RESET buttons are brought out to the device enclosure (3D-printed box) on separate wires anyway — so whether the board itself has a BOOT button does not matter for the choice.

**Known trade-off of the chosen board — regulator heating:** the built-in **AMS1117** linear regulator (5V→3.3V) on the D1 mini heats up to ~54°C in operation. This is not unique to the D1 mini — the same AMS1117 is used on WROOM-32 DevKit boards, but the small D1 mini board has less PCB copper for heat dissipation. 54°C is not critical for the regulator itself, but it is close to the softening temperature of PLA (used for the 3D-printed enclosure) — with a tight layout, the plastic may deform during long operation without ventilation.

**Risk accepted** — the build is used as is. If heating ever becomes a problem, two options are possible:
1. A ventilation hole in the enclosure above the regulator.
2. Bypassing/desoldering the built-in AMS1117 and supplying ready 3.3V from a separate external DC-DC regulator (similar to the SD module modification in `murmulator-vga-project-summary.md`, section 2).

## BlueRetro hardware build
- A DIY build based on the **ESP32 D1 mini (MH-ET LIVE, CH9102 USB-serial chip)** is used — homemade, not the ready-made BlueRetroHW board.
- **⚠️ There is no BOOT/IO0 button on the D1 mini board.** Unlike the full-size ESP32 DevKitC, the D1 mini physically has only the **RST/EN** button (module reset) — there is no separate BOOT button. BlueRetro functions (pairing, configuration reset, factory reset — see the "BOOT button (IO0)" section below) rely on IO0, so a **separate button between IO0 and GND must be added**.
  - In theory an external pull-up resistor is not required — the ESP32 enables an internal pull-up on IO0 (a strapping pin) in hardware at startup. The button simply shorts IO0 to GND when pressed.
  - **In practice the internal pull-up on the specific module proved unstable**, so in the final KiCad schematic the external resistor **R1 = 10 kΩ (from IO0 to +3.3V) is always fitted**, as a standard component rather than an optional fallback.

### BOOT button (IO0) — BlueRetro functions
⚠️ The timings and actions below apply to the firmware version in use (`v25.04_hw1`, see the "Firmware" section). In other BlueRetro versions the hold durations and results may differ — check the BlueRetro Wiki for the specific installed version.
- Short press (< 3 sec) — normal system reset.
- Hold 3–6 sec (IO17 LED blinks slowly) — start pairing mode.
- Hold 6–10 sec (IO17 LED blinks fast) — reset to default configuration.
- Hold > 30 sec — full ESP32 factory reset (factory firmware + settings reset).
- In pairing mode, a short press stops pairing / disconnects all Bluetooth devices.

## Pinout (consistent with murmulator-vga-project-summary.md)

**Topology:** ESP32 (BlueRetro) → J1/J2 connectors (JST XH 1x04, on the BlueRetro board) → adapter cable (JST XH 4-pin male → DE-9 female) → J6/J7 connectors (DE-9 male, on the Murmulator board) → Pico GPIO.

| Signal | ESP32 pin (BlueRetro) | JST XH J1 (P1) | JST XH J2 (P2) | DE-9 Murmulator J6 (P1) | DE-9 Murmulator J7 (P2) | Pico GPIO |
|---|---|---|---|---|---|---|
| LATCH (shared) | IO32 | pin 1 | pin 1 | pin 3 | pin 3 | GP15 |
| CLOCK port 1 | IO5 | pin 2 | — | pin 4 | — | GP14 |
| CLOCK port 2 | IO18 | — | pin 2 | — | pin 4 | GP14* |
| DATA port 1 | IO19 | pin 3 | — | pin 2 | — | GP16 |
| DATA port 2 | IO22 | — | pin 3 | — | pin 2 | GP17 |
| GND | ESP32 GND | pin 4 | pin 4 | pin 8 | pin 8 | GND |
| VCC (+5V) | — | not routed | not routed | pin 6 | pin 6 | **do not connect** |

**Adapter cable wiring (JST XH 4-pin male → DE-9 female), identical for both ports:**

| JST XH pin | Signal | DE-9 pin |
|---|---|---|
| 1 | LATCH | 3 |
| 2 | CLOCK | 4 |
| 3 | DATA | 2 |
| 4 | GND | 8 |

\* **CLOCK and LATCH are generated by the RP2040 (the Murmulator acts as host/console)** — each is a single physical signal (GP14/GP15) routed to both J6 and J7 connectors simultaneously. IO5 and IO18 on the ESP32 (BlueRetro emulates the joystick/slave) are two **inputs** listening to this signal, not two independent generators. No electrical conflict (bus contention) arises from joining them, since the RP2040 is the only active driver of the line. The BlueRetro firmware internally treats IO5/IO18 as two independent CLOCK inputs (for consoles where the P1/P2 CLOCK lines are not physically joined) — when connected to the Murmulator both inputs necessarily receive the same physical signal.

VCC (pin 6, Murmulator DE-9) is intentionally left unconnected: the ESP32 inside BlueRetro runs on 3.3V logic, and the signal lines go directly to the Pico GPIO without level shifters; BlueRetro power is provided separately, through the board's own J3 connector (see the "BlueRetro power" section). The JST XH J1/J2 connectors (joystick ports on the BlueRetro side) have no +5V line at all — only 4 signals (LATCH/CLOCK/DATA/GND).

## BlueRetro power (ESP32 module)
- The ESP32 D1 mini (with a built-in AMS1117 regulator, 5V→3.3V) can be powered in two ways — separately or simultaneously:
  1. **Via J3 on the BlueRetro board** — from the Murmulator's J2 connector (a tap of "raw" +5V from the external PSU, upstream of the Murmulator's diode D1, see `murmulator-vga-project-summary.md`, section 10) → Schottky diode D1 = 1N5819 on the BlueRetro board → D1 mini 5V pin. Because of the diode drop, the D1 mini 5V pin receives less than 5V (~4.5–4.7V).
  2. **Via the micro-USB port on the D1 mini** (from a PC or a USB adapter).
- **Connecting J3 and micro-USB at the same time is acceptable.** The D1 mini has no protection diode: its 5V pin is connected directly to the micro-USB VBUS and to the input of the 3.3V regulator. Isolation is provided only by the Schottky diode D1 = 1N5819 at the J3 input: it blocks current from USB into the Murmulator PSU, and the voltage after it is below 5V, so when both are connected the load is taken by USB. Safety condition — the PSU voltage minus the drop across D1 (~0.15–0.25V at low current) must stay below the USB port voltage; otherwise the PSU will back-feed the computer's VBUS. With a PSU of ~5.0V the condition is met with margin.
- **⚠️ Limitation when powered only via J3:** BlueRetro and both joysticks work only when the external PSU is connected to the Murmulator. The YD-RP2040 has no accessible USB VBUS upstream of the BAT54C combining diode, so BlueRetro cannot be powered from the Murmulator's USB. When powered via the D1 mini micro-USB, this limitation does not apply.
- **Measured (multimeter):** peak current draw of the ESP32 on the 5V bus with the BT radio active — **~155 mA**. Power via J2 (on the Murmulator board) → J3 (on the BlueRetro board) bypasses the Murmulator's BAT54C diode and Vout node (see `murmulator-vga-project-summary.md`), so this load does not share the current budget with the PS/2 keyboard and is not limited by the BAT54C rating (~150–300 mA per leg) — the current margin is sufficient.
- The GND of the signal lines (LATCH/CLOCK/DATA) is shared with the Murmulator in any power configuration — via the J1/J2 connectors (JST XH) and the adapter cables to J6/J7.

## Input power protection, RESET, and decoupling

**External 5V connector (J3) and protection diode D1:**
- **J3** — a separate 2-pin connector ("External 5V Power Connector") through which power from the external PSU 5V bus is brought onto the board (see the "BlueRetro power" section above).
- **D1 = 1N5819** (Schottky, 40V/1A) is placed between J3 and the +5V bus: anode on the J3 side, cathode on the +5V side. Function — reverse-polarity protection / input isolation (analogous to the BAT54C diode-OR on the Murmulator itself, see `murmulator-vga-project-summary.md`, section 10).

**RESET button (SW2):**
- A separate button **SW2** that shorts the ESP32 module's **RST** to GND — a standard hardware reset of the module, independent of the BOOT/IO0 logic (see the BOOT button function list above).

**Decoupling capacitors (bulk + bypass on both power rails):**

| Rail | Bulk (electrolytic) | Bypass (ceramic) |
|---|---|---|
| +5V (input, after J3/D1) | C5 = 470 µF | C6 = 100 nF |
| +3V3 (ESP32 module regulator output) | C8 = 220 µF | C7 = 100 nF |

Both capacitors on each rail are connected in parallel between the rail and GND — the classic pair of "bulk filtering + high-frequency decoupling".

---

## LED indication subsystem (final, hardware-verified)

According to the BlueRetro Wiki (LED usage sections), indication consists of two types of LEDs: **one global-status LED on IO17** and up to **four port-status LEDs** (one per port). This build implements the global LED + two port LEDs (for both joystick ports, P1/P2).

**Note on IO17 vs the board's built-in LED:** on some ESP32 DevKitC/D1 mini boards the built-in LED sits on IO2, but in the BlueRetro firmware this pin is used for the auto-programming circuit — so indication requires a separate external LED on IO17 specifically, rather than relying on the board's built-in power/status LED.

**ESP32 pin assignment:**

| ESP32 IO | Function | LED | Connection |
|---|---|---|---|
| IO17 | Global status (adapter status / error / pairing) | D3, blue | two-resistor pull-up circuit (direct) |
| IO2 | Port 1 status | D4, green | via MOSFET Q1 (2N7000) |
| IO4 | Port 2 status | D5, green | via MOSFET Q2 (2N7000) |

IO2/IO4/IO17 are all ESP32 strapping pins. Only the port LEDs D4 (IO2) and D5 (IO4) are driven through MOSFETs — a requirement of this BlueRetro hardware revision so that the LED load does not interfere with booting; IO17 (D3) uses a separate pull-up circuit without a MOSFET (see above). Ports 3/4 (if expanded) are IO12/IO15, but in PlayStation mode they are reassigned to analog-mode indication; not relevant for NES mode.

**Behavior (confirmed by a real test):**
- Power on, no error → auto-pairing: the global LED (IO17) **pulses** + the LED of the first available port (IO2) **pulses**; the second port (IO4) is off.
- 1st gamepad connected → IO17 goes off, port 1 (IO2) **solid**.
- 2nd gamepad connected → port 2 (IO4) **solid**, IO17 stays off.
- Gamepad disconnected → its port LED goes off; when a port is freed, the adapter returns to pairing (global + first free port pulse again).

### Global-status LED circuit IO17 (two-resistor variant)

⚠️ Differs from the official single-resistor circuit in the wiki (R36 ≈ 65 Ω–1 kΩ, LED directly between the node and GND). This build uses **two resistors**, which improves behavior:

```
+3V3 --[R2 360R]--+-- IO17 (U1 pin 25)
                  |
                  +--[R3 150R]--[D3 anode >|< cathode]-- GND
```
IO17 is connected to the node between R2 and R3 (on the LED anode side), not to the GND side.

**Resistor roles:**
- **R2 = 360R** — pull-up 3.3V→IO17. Provides fail-safe behavior (in high-Z the LED glows dimly) and determines the parasitic current sunk into the GPIO at LOW. It **does not affect** the operating brightness.
- **R3 = 150R** — series current-limiting resistor for the LED. Sets the brightness in HIGH-PWM (pulsing/solid). Limits the current when actively driven push-pull HIGH.

**Logic (fail-safe by default):**
- IO17 by default (not configured, high-Z/input) → R2 pulls the node up to 3.3V → **the LED glows dimly on its own**, without any firmware command.
- After a successful start, the firmware **explicitly sets IO17 as an output LOW** → node to 0V → **the LED turns off**.
- Purpose of the inversion: if the firmware fails to boot (crash before initialization), IO17 stays high-Z and the LED **keeps glowing** = error indication. In the classic circuit such a failure would be indistinguishable from the normal "off" state.
- Pulsing/status: the firmware switches IO17 to PWM via LEDC (~200 µs, duty 0–20%), creating a "breathing" effect. Confirmed with an oscilloscope.

### Port-status LED circuit (IO2/IO4, via MOSFET)

```
+3V3 --[D4/D5 anode >|< cathode]--[R4/R5 510R]-- drain Q1/Q2
                                                 gate  -- IO2/IO4
                                                 source-- GND
```
With IO2/IO4 HIGH → MOSFET on → LED lit. With the MOSFET off, no current flows at all — there is **no** "current sunk into the GPIO" issue here (unlike IO17), so the port LEDs can run at operating current without regard to GPIO load.

### Final values and currents (measured Vf)

Vf was measured with a multimeter (voltmeter) across the LED through 510R to 3.3V (high input impedance → true operating point): **blue Vf = 2.6 V @ ~1.4 mA, green Vf = 2.4 V @ ~1.76 mA.**

| LED | Color | Vf | Circuit | Current | State |
|---|---|---|---|---|---|
| D3 (IO17) | blue | 2.6 V | R3 = 150R | ~4.0–4.5 mA | HIGH-PWM (pulsing/status) |
| D3 (IO17) | blue | 2.6 V | R2 = 360R | ~9.2 mA | LOW — current sunk into GPIO (depends only on R2) |
| D3 (IO17) | blue | 2.6 V | R2+R3 = 510R | ~1.37 mA | high-Z — fail-safe (start-up error) |
| D4/D5 (ports) | green | 2.4 V | R4/R5 = 510R | ~1.76 mA | solid (port connected) |

**Brightness balance:** the green port LEDs run at a lower current (~1.76 mA) than the blue status LED (~4.5 mA), but because the eye is most sensitive to green (~555 nm) and weakly sensitive to blue, they look comparable. R4/R5 = 510R — with a lower value (150R) the green would become brighter than the blue, breaking the balance.

**Visual check:** when blue (IO17) and green (port 1) are lit at the same time during pairing, their brightness is comparable. If needed, R4/R5 can be lowered to ~330R (~2.7 mA) — but not lower.

**Voltage headroom:** the blue LED has little headroom (3.3 − 2.6 = 0.7 V), so its brightness is sensitive to dips on the 3.3V rail — at 3.2 V the HIGH current drops to ~4 mA, which is still fine.

## Oscilloscope signal verification (confirmed)

📄 The full set of oscillograms (LATCH, "no button pressed", and pressing each of the 8 Xbox One gamepad buttons in turn), with a description of the oscilloscope connection and settings, is in the document **`blueretro-xbox-one-nes-oscillograms_EN.docx`** (the original screenshots are in the `XBox One as NES Joystick Debugging` folder).

**CLOCK (GP14 → IO5/IO18):** period 80 µs (≈12.5 kHz), 50% duty cycle (HIGH = LOW = 40 µs), amplitude 0V ↔ 3.3V, clean edges.

**LATCH (GP15 → IO32):** repetition period 1200 µs (≈833 Hz), pulse width 40 µs, amplitude 0V ↔ 3.3V.

- The LATCH pulse width (40 µs) equals one CLOCK phase — typical for latching the parallel-loaded button state before a series of shift clocks.
- One LATCH period fits 1200 / 80 = 15 full CLOCK cycles — enough to read the 8-bit register with margin.
- Polling rate ~833 Hz (confirmed with an oscilloscope) — noticeably higher than the classic NES/Famicom (~60 Hz, synchronized with the frame).
- The 0V/3.3V amplitude on both lines confirms correct operation of the "one driver (Pico) — receivers (ESP32)" topology, without bus contention.

**DATA (IO19/IO22 → GP16/GP17):** when buttons are pressed on the Xbox One gamepad (A, X, View, Menu, D-pad Up/Down/Left/Right), a **LOW (~0V) pulse 80 µs long** is seen on the DATA line — exactly one CLOCK period.
**The first button is output without a clock pulse:** as soon as the Murmulator asserts LATCH, the chip immediately places the value of button A on the DATA line (this is bit 0). The following buttons (X, View, Menu, etc.) are output one by one on each subsequent CLOCK pulse.

- The protocol uses **inverted logic**: LOW = button pressed, HIGH (3.3V) = button released — the standard convention for an NES/Dendy-compatible shift register.
- The pulse width (80 µs) exactly matches the CLOCK period — confirming that each bit is placed on DATA for exactly one shift clock, synchronously and without phase shift.
- The correspondence "physical Xbox button pressed → LOW pulse in the expected clock slot" confirms the correct BlueRetro mapping (Xbox One HID → NES bits) and correct reading by the Murmulator on the RP2040 side.

**DATA bit order in the NES shift register and Xbox One mapping (confirmed):**

| Clock | Bit | Xbox One button | Role (NES bit) |
|---|---|---|---|
| 1 | 0 | A | A |
| 2 | 1 | X | B |
| 3 | 2 | View | Select |
| 4 | 3 | Menu | Start |
| 5 | 4 | D-pad Up | Up |
| 6 | 5 | D-pad Down | Down |
| 7 | 6 | D-pad Left | Left |
| 8 | 7 | D-pad Right | Right |

The bit order **A, B, Select, Start, Up, Down, Left, Right** is the standard, canonical bit output order of the original NES controller (the same order in which the NES console historically read the 4021 register). The match confirms that BlueRetro in `GamePad`/NES mode emulates the classic protocol one-to-one, without changing the bit order, and that the Murmulator reads them in the same order.

The verification confirms both the electrical integrity of the CLOCK/LATCH signals and the correct phase alignment of DATA relative to CLOCK — data is sampled at the right point of the clock cycle.

## Firmware (verified, working configuration)

**Firmware version:** `v25.04_hw1.zip` (archive from [GitHub Releases](https://github.com/darthcloud/BlueRetro/releases)) — the HW1 specification is used (see the "BlueRetro hardware build" section).

**Files from the archive:**
- `bootloader.bin`
- `partition-table.bin`
- `ota_data_initial.bin`
- `BlueRetro_hw1_nes.bin` (system-specific firmware for NES)

**Flashing command (Windows, via PlatformIO Core):**

```
pio pkg exec -- esptool.py -p COM6 -b 460800 --before default_reset --after hard_reset --chip esp32 write_flash --flash_mode dio --flash_size detect --flash_freq 40m 0x1000 bootloader.bin 0x8000 partition-table.bin 0xD000 ota_data_initial.bin 0x10000 BlueRetro_hw1_nes.bin
```

Port `COM6` is for a specific board instance — check it in Windows Device Manager each time you flash.

**Note:** when calling `python esptool.py ...` directly (not via `pio pkg exec`), esptool dependencies may be missing, because the system Python does not see the environment where PlatformIO installed them — the `pio pkg exec --` command avoids this problem by using the correct environment automatically.

**Full flash erase:**
```
pio pkg exec -- esptool.py -p COM6 --chip esp32 erase_flash
```

**Serial Monitor Debug:**
```
pio device monitor -p COM6 -b 921600
```

**SecureCRT Serial Monitor settings:**
```
Connection:
  Serial:
    Port: COM6
    Baud rate: 921600
Terminal:
  Emulation:
    Modes:
      [v] New line mode
```

### Initial setup after flashing (BlueRetro Web Configurator)

After flashing, configuration via Web Config may be needed — in this case the build worked with the default settings; the configuration below is given for verification/reference.

**Address:** [https://blueretro.io/](https://blueretro.io/)

⚠️ BlueRetro configuration is available only when **no controller is connected** — this is intentional, so as not to take airtime away from the gamepads during play.

**Procedure:**
1. Open **"BlueRetro Advance config"**.
2. Click **[Connect BlueRetro]** — repeat the click if needed until the connection is established.
3. A pop-up window with a list of Bluetooth devices opens — select the BlueRetro device and click **[Pair]**.
4. **Global Config:**
   - System: `NES`
   - Multitap: `None`
5. **Output Config:**
   - Output 1 → Mode: `GamePad`, Accessories: `None`
   - Output 2 → Mode: `GamePad`, Accessories: `None`
6. **[Save]**

## Pairing and disconnecting gamepads

Practical instructions for pairing and disconnecting/unpairing Bluetooth gamepads are in a separate document, **`blueretro-murmulator-user-guide_EN.md`**.

## Open questions (require clarification/verification)
*(none at the moment)*

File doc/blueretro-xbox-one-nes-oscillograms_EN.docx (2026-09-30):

# BlueRetro: Xbox One gamepad as an NES joystick — oscilloscope verification

Document version: 1.0 · Date: 2026-10-01 · Measurement date: 2026-09-30

Related document: blueretro-murmulator-project-summary_EN.md, section "Oscilloscope signal verification (confirmed)".

# 1. Test objective

Verify that BlueRetro (ESP32 D1 mini, firmware v25.04_hw1, NES / GamePad mode) correctly passes Xbox One gamepad button presses to the Murmulator using the NES shift-register protocol: each button appears on the DATA line in its own bit position, in the correct phase relative to CLOCK and LATCH.

# 2. Oscilloscope connection and settings

Oscilloscope input | Signal | Note
CH1 (yellow) | DATA | In Fig. 1 (01_LATCH_signal) CH1 is connected to LATCH
CH2 (blue) | CLOCK | All figures
EXT TRIG | LATCH | Triggering on the rising edge of LATCH

Parameter | Value
Vertical scale CH1 / CH2 | 2 V/div / 2 V/div
Timebase | 200 µs/div
Trigger | Ext, rising edge, level 1.08 V
Trigger point position (T marker) | ≈1 division from the left edge of the screen

Capture order: Fig. 1 — LATCH signal; Fig. 2 — no button pressed; Figs. 3–10 — exactly one button pressed at a time, in NES bit order (from bit 0 to bit 7).

# 3. Expected NES protocol behavior

- Inverted logic: LOW = button pressed, HIGH = released.
- On the LATCH edge, bit 0 (button A) is placed on DATA immediately — without a clock pulse.
- Each subsequent CLOCK pulse shifts the register: bits 1–7 appear one per clock (≈80 µs per bit).
- Bit order: A, B, Select, Start, Up, Down, Left, Right.

# 4. Summary of results

Fig. | Xbox One button | NES button | Bit | Result
1 | — (LATCH signal) | — | — | Period ≈1200 µs, pulse ≈40 µs
2 | nothing pressed | — | — | DATA = HIGH in all 8 bits ✔
3 | A | A | 0 | LOW at bit position 0 ✔
4 | X | B | 1 | LOW at bit position 1 ✔
5 | View | Select | 2 | LOW at bit position 2 ✔
6 | Menu | Start | 3 | LOW at bit position 3 ✔
7 | D-pad Up | Up | 4 | LOW at bit position 4 ✔
8 | D-pad Down | Down | 5 | LOW at bit position 5 ✔
9 | D-pad Left | Left | 6 | LOW at bit position 6 ✔
10 | D-pad Right | Right | 7 | LOW at bit position 7 ✔

Result: all 8 buttons appear on the DATA line in the expected bit position; the Xbox One → NES mapping (A→A, X→B, View→Select, Menu→Start, D-pad→Up/Down/Left/Right) and the bit order are confirmed (confirmed).

# 5. Additional observation: CLOCK polling mode

In Figs. 1–2 CLOCK runs continuously and LATCH repeats every ≈1200 µs. In Figs. 3–10 LATCH is followed by a burst of ≈12–13 CLOCK pulses, after which the CLOCK line stays HIGH and the next LATCH does not appear within the screen window (≈1.8 ms after the trigger). In other words, the Murmulator polling period differed between captures. This does not affect reading correctness: in both modes there are more than 8 clocks. The reason for the difference has not been established.

# 6. Oscillograms

## Fig. 1. LATCH signal

File: 01_LATCH_signal.jpg · CH1 = LATCH, CH2 = CLOCK, EXT TRIG = LATCH

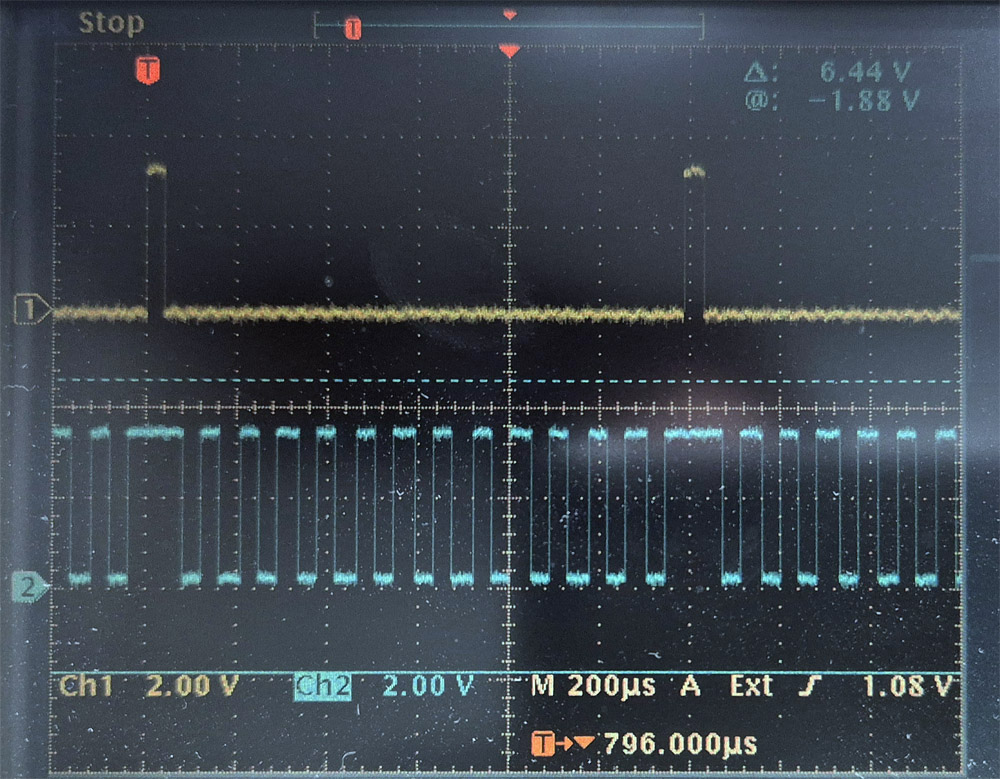
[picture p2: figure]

- CH1 (LATCH): short positive pulses ≈40 µs wide with a period of ≈1200 µs (≈6 divisions) — polling rate ≈833 Hz.
- CH2 (CLOCK): a continuous clock train with a period of ≈80 µs (≈12.5 kHz); around the LATCH pulse the CLOCK line is held HIGH.

## Fig. 2. No button pressed

File: 02_no_button_pressed.jpg · CH1 = DATA, CH2 = CLOCK, EXT TRIG = LATCH

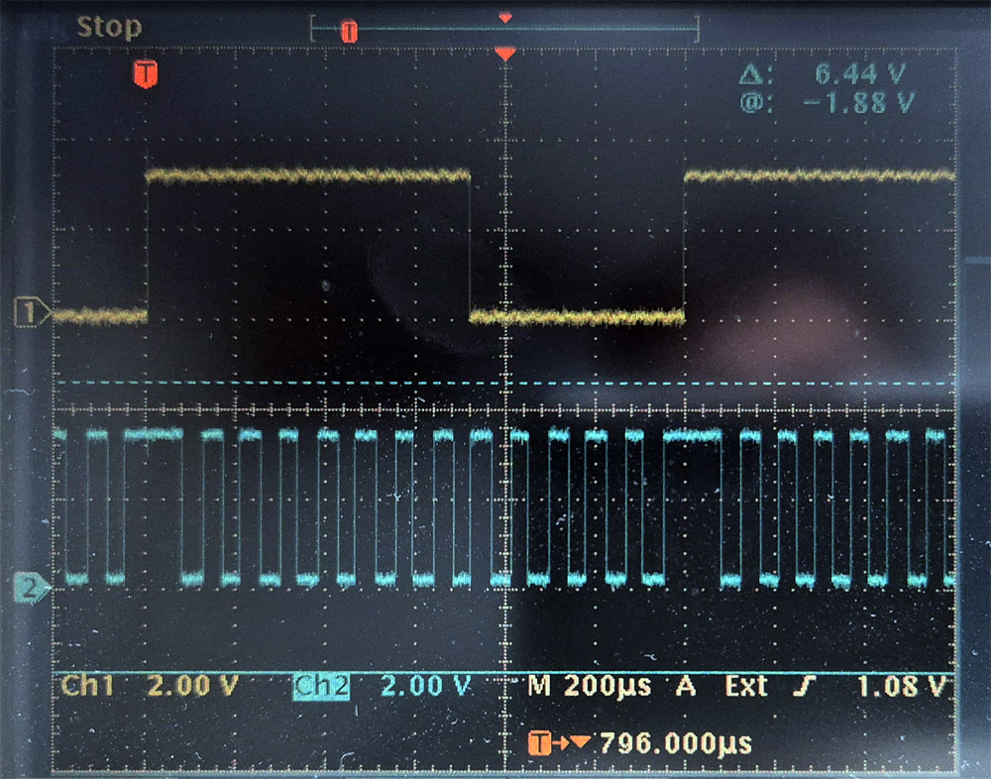
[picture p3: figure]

- After the LATCH edge the DATA line stays HIGH for all 8 bits (≈700 µs) — all buttons released.
- After the 8th bit DATA goes LOW and stays there until the next LATCH; at the next LATCH HIGH is loaded again. This matches the original NES controller: after 8 bits the shift register outputs LOW.

## Fig. 3. Button A (Xbox A) — bit 0

File: 03_A_(xbox_A).jpg · CH1 = DATA, CH2 = CLOCK, EXT TRIG = LATCH

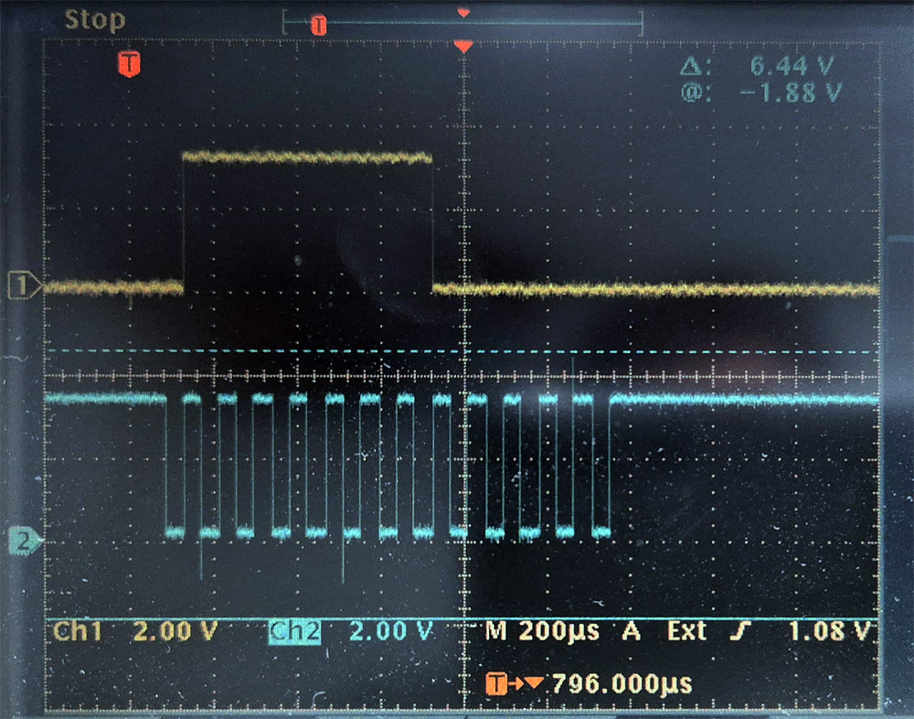
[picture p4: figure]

- DATA is LOW immediately after the LATCH edge, before the first CLOCK pulse — bit 0 is placed on the line by the latch, without a clock pulse.
- With the first CLOCK pulse DATA goes HIGH (bits 1–7 — buttons released); after the 8th bit — LOW.

## Fig. 4. Button B (Xbox X) — bit 1

File: 04_B_(xbox_X).jpg · CH1 = DATA, CH2 = CLOCK, EXT TRIG = LATCH

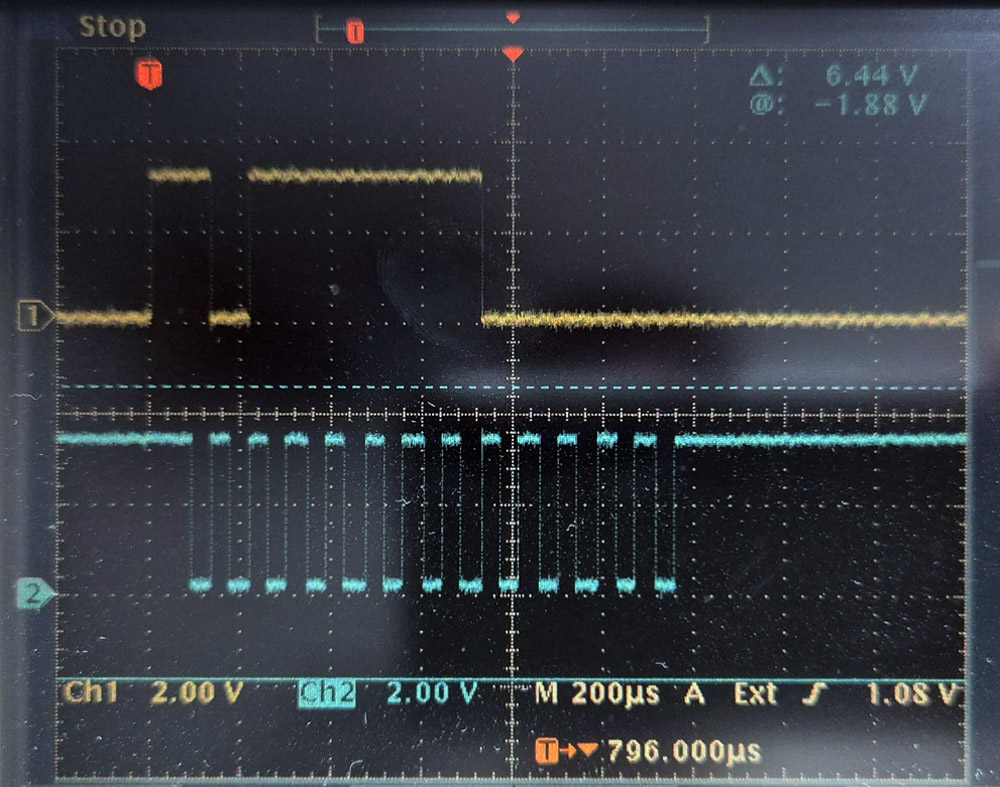
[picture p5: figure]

- A LOW pulse ≈80 µs long (one CLOCK period) in the second bit position after LATCH.

## Fig. 5. Button Select (Xbox View) — bit 2

File: 05_SELECT_(xbox_view).jpg · CH1 = DATA, CH2 = CLOCK, EXT TRIG = LATCH

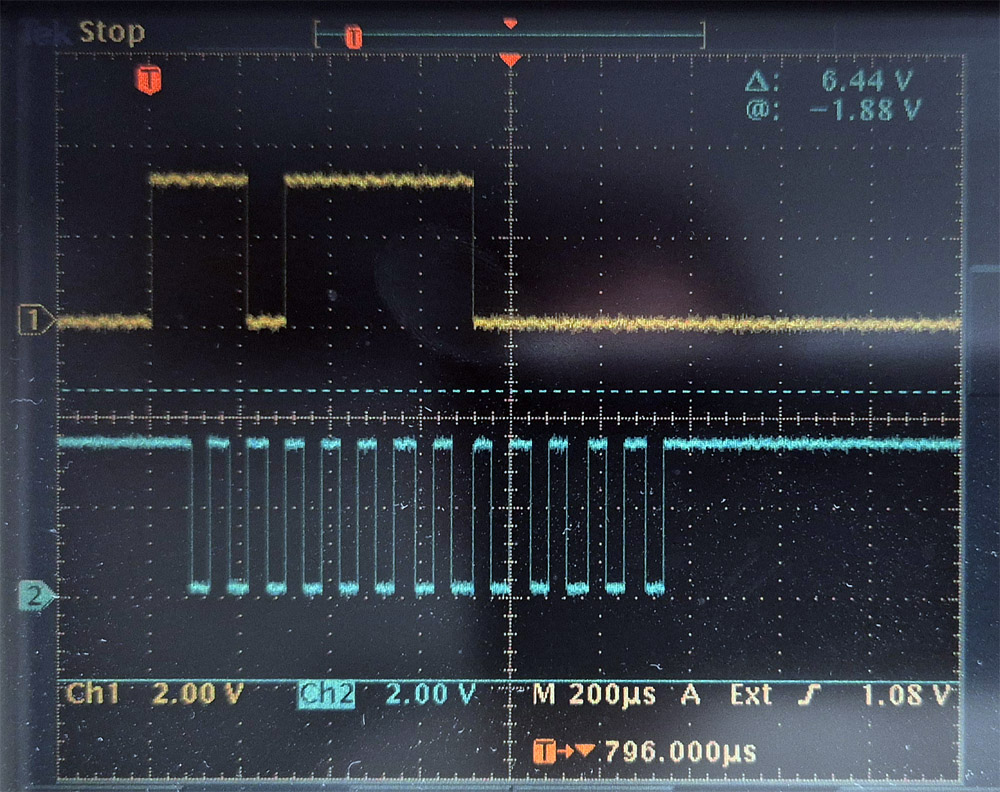
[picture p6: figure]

- A ≈80 µs LOW pulse in the third bit position after LATCH.

## Fig. 6. Button Start (Xbox Menu) — bit 3

File: 06_START_(xbox_menu).jpg · CH1 = DATA, CH2 = CLOCK, EXT TRIG = LATCH

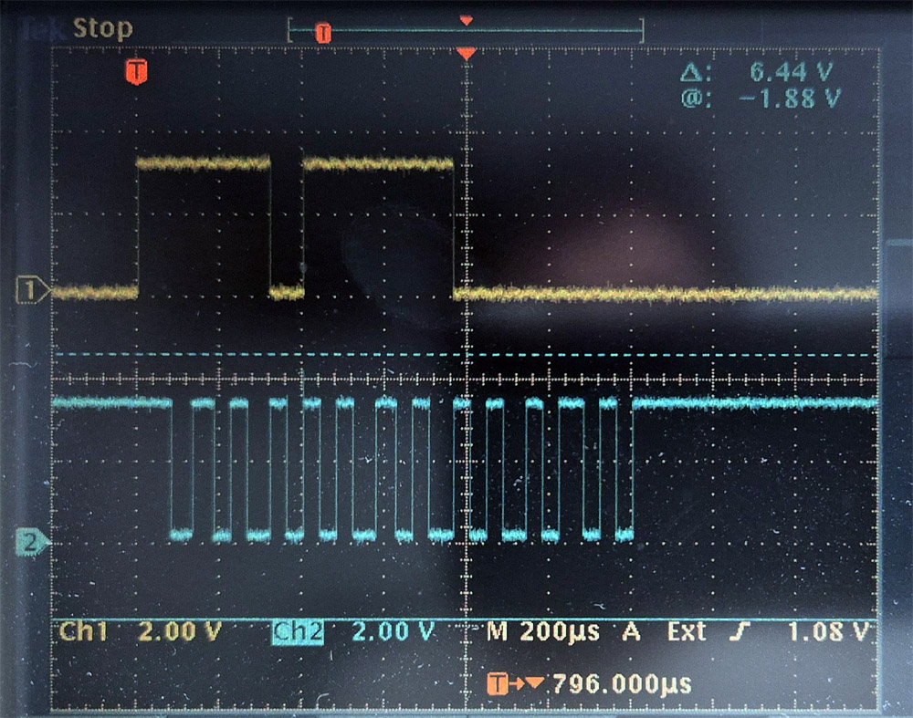
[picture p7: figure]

- A ≈80 µs LOW pulse in the fourth bit position after LATCH.

## Fig. 7. Up (Xbox D-pad Up) — bit 4

File: 07_up_(xbox_dpad_up).jpg · CH1 = DATA, CH2 = CLOCK, EXT TRIG = LATCH

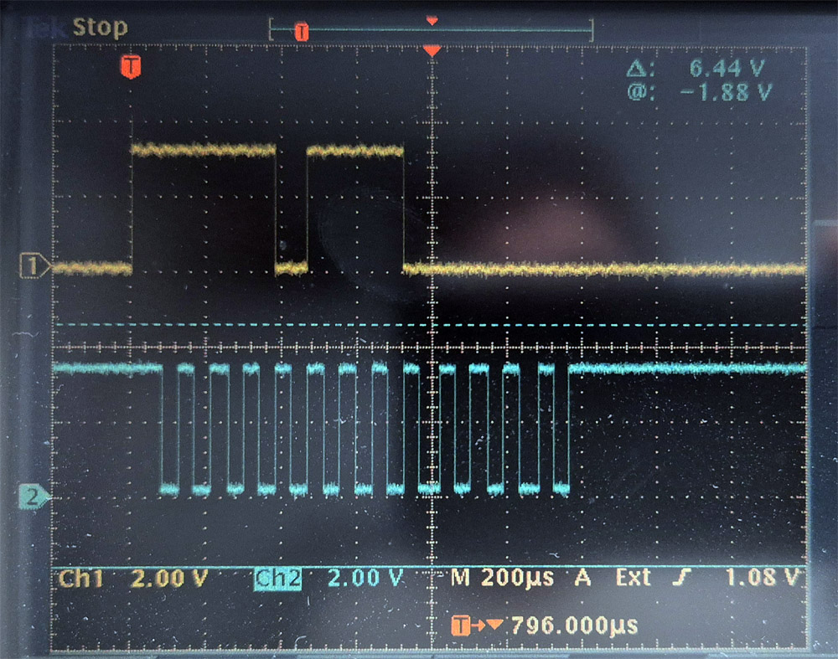
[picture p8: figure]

- A ≈80 µs LOW pulse in the fifth bit position after LATCH.

## Fig. 8. Down (Xbox D-pad Down) — bit 5

File: 08_down_(xbox_dpad_down).jpg · CH1 = DATA, CH2 = CLOCK, EXT TRIG = LATCH

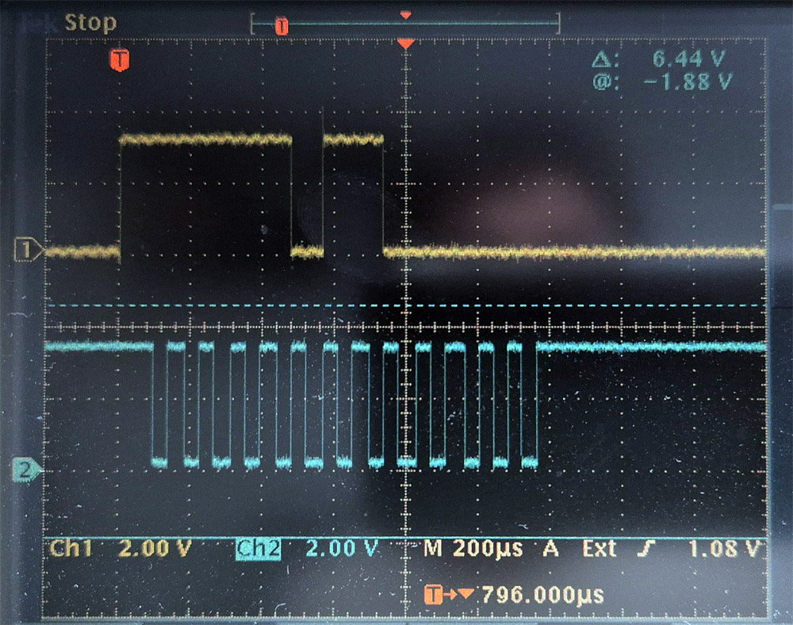
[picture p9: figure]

- A ≈80 µs LOW pulse in the sixth bit position after LATCH.

## Fig. 9. Left (Xbox D-pad Left) — bit 6

File: 09_left_(xbox_dpad_left).jpg · CH1 = DATA, CH2 = CLOCK, EXT TRIG = LATCH

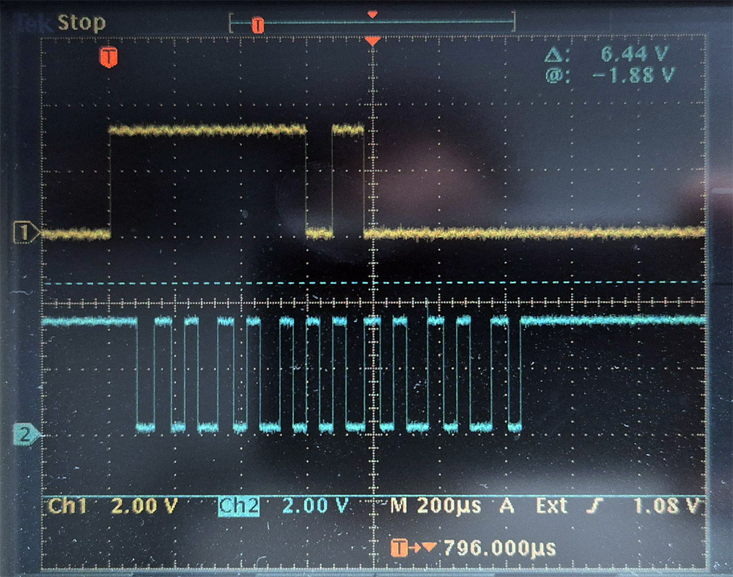
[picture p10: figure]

- A ≈80 µs LOW pulse in the seventh bit position after LATCH.

## Fig. 10. Right (Xbox D-pad Right) — bit 7

File: 10_right_(xbox_dpad_right).jpg · CH1 = DATA, CH2 = CLOCK, EXT TRIG = LATCH

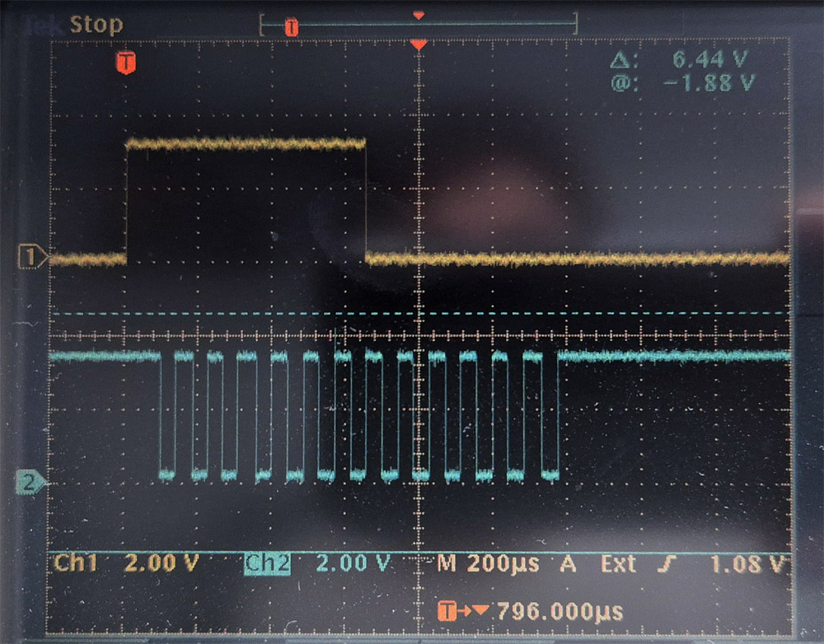
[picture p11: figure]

- Bit 7 is the last one, so its LOW merges with the LOW level after the 8th bit: there is no separate pulse; the HIGH section ends one clock earlier than with "no button pressed" (see Fig. 2).

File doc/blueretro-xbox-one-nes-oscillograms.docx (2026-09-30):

# BlueRetro: геймпад Xbox One как NES-джойстик — проверка осциллографом

Версия документа: 1.0 · Дата: 2026-10-01 · Дата измерений: 2026-09-30

Связанный документ: blueretro-murmulator-project-summary.md, раздел «Проверка сигналов осциллографом (подтверждено)».

# 1. Цель теста

Проверить, что BlueRetro (ESP32 D1 mini, прошивка v25.04_hw1, режим NES / GamePad) корректно передаёт нажатия геймпада Xbox One на Мурмулятор по протоколу сдвигового регистра NES: каждая кнопка появляется на линии DATA в своей битовой позиции, в правильной фазе относительно CLOCK и LATCH.

# 2. Подключение и настройки осциллографа

Вход осциллографа | Сигнал | Примечание
CH1 (жёлтый) | DATA | На рис. 1 (01_LATCH_signal) CH1 подключён к LATCH
CH2 (голубой) | CLOCK | Все рисунки
EXT TRIG | LATCH | Синхронизация по нарастающему фронту LATCH

Параметр | Значение
Вертикальная шкала CH1 / CH2 | 2 В/дел / 2 В/дел
Развёртка | 200 мкс/дел
Триггер | Ext, нарастающий фронт, уровень 1.08 В
Положение точки запуска (метка T) | ≈1 деление от левого края экрана

Порядок съёмки: рис. 1 — сигнал LATCH; рис. 2 — ни одна кнопка не нажата; рис. 3–10 — поочерёдно нажата ровно одна кнопка в порядке битов NES (от бита 0 до бита 7).

# 3. Ожидаемое поведение протокола NES

- Инверсная логика: LOW = кнопка нажата, HIGH = отпущена.
- По фронту LATCH на DATA сразу выставляется бит 0 (кнопка A) — без тактового импульса.
- Каждый следующий импульс CLOCK сдвигает регистр: биты 1–7 появляются по одному на такт (≈80 мкс на бит).
- Порядок битов: A, B, Select, Start, Up, Down, Left, Right.

# 4. Сводка результатов

Рис. | Кнопка Xbox One | NES-кнопка | Бит | Результат
1 | — (сигнал LATCH) | — | — | Период ≈1200 мкс, импульс ≈40 мкс
2 | ничего не нажато | — | — | DATA = HIGH во всех 8 битах ✔
3 | A | A | 0 | LOW в позиции бита 0 ✔
4 | X | B | 1 | LOW в позиции бита 1 ✔
5 | View | Select | 2 | LOW в позиции бита 2 ✔
6 | Menu | Start | 3 | LOW в позиции бита 3 ✔
7 | D-pad Up | Up | 4 | LOW в позиции бита 4 ✔
8 | D-pad Down | Down | 5 | LOW в позиции бита 5 ✔
9 | D-pad Left | Left | 6 | LOW в позиции бита 6 ✔
10 | D-pad Right | Right | 7 | LOW в позиции бита 7 ✔

Итог: все 8 кнопок появляются на линии DATA в ожидаемой битовой позиции; маппинг Xbox One → NES (A→A, X→B, View→Select, Menu→Start, D-pad→Up/Down/Left/Right) и порядок битов подтверждены (подтверждено).

# 5. Дополнительное наблюдение: режим опроса CLOCK

На рис. 1–2 CLOCK идёт непрерывно, а LATCH повторяется каждые ≈1200 мкс. На рис. 3–10 после LATCH следует пачка из ≈12–13 тактов CLOCK, после чего линия CLOCK остаётся в HIGH, а следующий LATCH в окно экрана (≈1.8 мс после запуска) не попадает. То есть период опроса Мурмулятора между съёмками отличался. На корректность чтения это не влияет: в обоих режимах тактов больше 8. Причина разницы не установлена.

# 6. Осциллограммы

## Рис. 1. Сигнал LATCH

Файл: 01_LATCH_signal.jpg · CH1 = LATCH, CH2 = CLOCK, EXT TRIG = LATCH


- CH1 (LATCH): короткие положительные импульсы длительностью ≈40 мкс с периодом ≈1200 мкс (≈6 делений) — частота опроса ≈833 Гц.
- CH2 (CLOCK): непрерывная последовательность тактов с периодом ≈80 мкс (≈12.5 кГц); вокруг импульса LATCH линия CLOCK удерживается в HIGH.

## Рис. 2. Ни одна кнопка не нажата

Файл: 02_no_button_pressed.jpg · CH1 = DATA, CH2 = CLOCK, EXT TRIG = LATCH


- После фронта LATCH линия DATA находится в HIGH в течение всех 8 бит (≈700 мкс) — все кнопки отпущены.
- После 8-го бита DATA переходит в LOW и остаётся там до следующего LATCH; на следующем LATCH снова загружается HIGH. Это поведение совпадает с оригинальным NES-контроллером: после 8 бит сдвиговый регистр выдаёт LOW.

## Рис. 3. Кнопка A (Xbox A) — бит 0

Файл: 03_A_(xbox_A).jpg · CH1 = DATA, CH2 = CLOCK, EXT TRIG = LATCH


- DATA в LOW сразу после фронта LATCH, ещё до первого импульса CLOCK — бит 0 выставляется на линию защёлкой, без тактового импульса.
- С первым тактом CLOCK DATA переходит в HIGH (биты 1–7 — кнопки отпущены), после 8-го бита — LOW.

## Рис. 4. Кнопка B (Xbox X) — бит 1

Файл: 04_B_(xbox_X).jpg · CH1 = DATA, CH2 = CLOCK, EXT TRIG = LATCH


- Импульс LOW длительностью ≈80 мкс (один такт CLOCK) во второй битовой позиции после LATCH.

## Рис. 5. Кнопка Select (Xbox View) — бит 2

Файл: 05_SELECT_(xbox_view).jpg · CH1 = DATA, CH2 = CLOCK, EXT TRIG = LATCH


- Импульс LOW ≈80 мкс в третьей битовой позиции после LATCH.

## Рис. 6. Кнопка Start (Xbox Menu) — бит 3

Файл: 06_START_(xbox_menu).jpg · CH1 = DATA, CH2 = CLOCK, EXT TRIG = LATCH


- Импульс LOW ≈80 мкс в четвёртой битовой позиции после LATCH.

## Рис. 7. Up (Xbox D-pad Up) — бит 4

Файл: 07_up_(xbox_dpad_up).jpg · CH1 = DATA, CH2 = CLOCK, EXT TRIG = LATCH


- Импульс LOW ≈80 мкс в пятой битовой позиции после LATCH.

## Рис. 8. Down (Xbox D-pad Down) — бит 5

Файл: 08_down_(xbox_dpad_down).jpg · CH1 = DATA, CH2 = CLOCK, EXT TRIG = LATCH


- Импульс LOW ≈80 мкс в шестой битовой позиции после LATCH.

## Рис. 9. Left (Xbox D-pad Left) — бит 6

Файл: 09_left_(xbox_dpad_left).jpg · CH1 = DATA, CH2 = CLOCK, EXT TRIG = LATCH


- Импульс LOW ≈80 мкс в седьмой битовой позиции после LATCH.

## Рис. 10. Right (Xbox D-pad Right) — бит 7

Файл: 10_right_(xbox_dpad_right).jpg · CH1 = DATA, CH2 = CLOCK, EXT TRIG = LATCH


- Бит 7 — последний, поэтому его LOW сливается с уровнем LOW после 8-го бита: отдельного импульса нет, участок HIGH заканчивается на один такт раньше, чем при «ничего не нажато» (см. рис. 2).

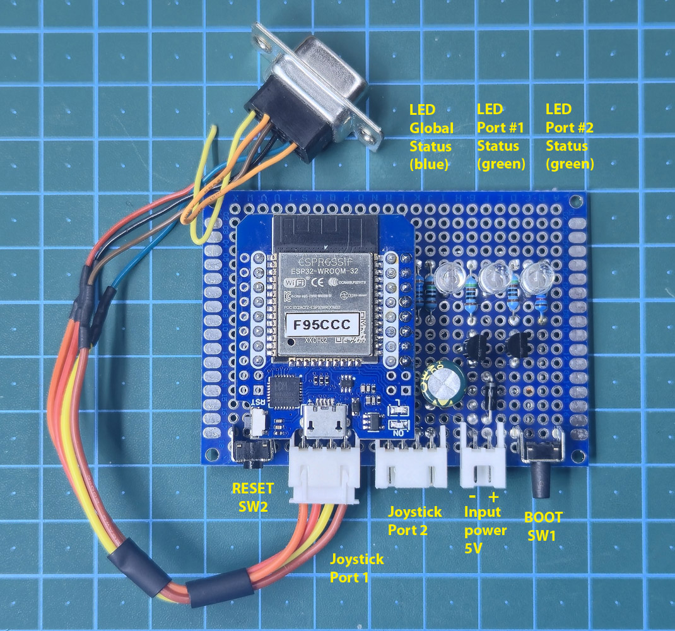
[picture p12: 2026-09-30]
doc/BlueRetro_PCB_front_notes.jpg

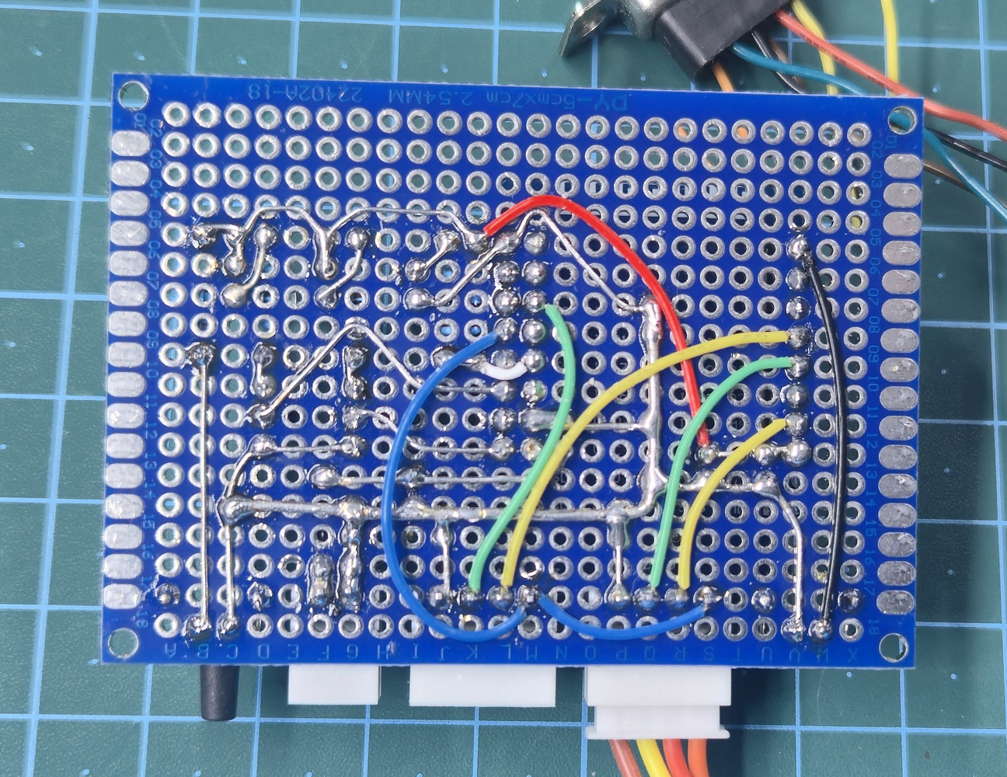
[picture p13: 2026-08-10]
doc/BlueRetro_PCB_back.jpg

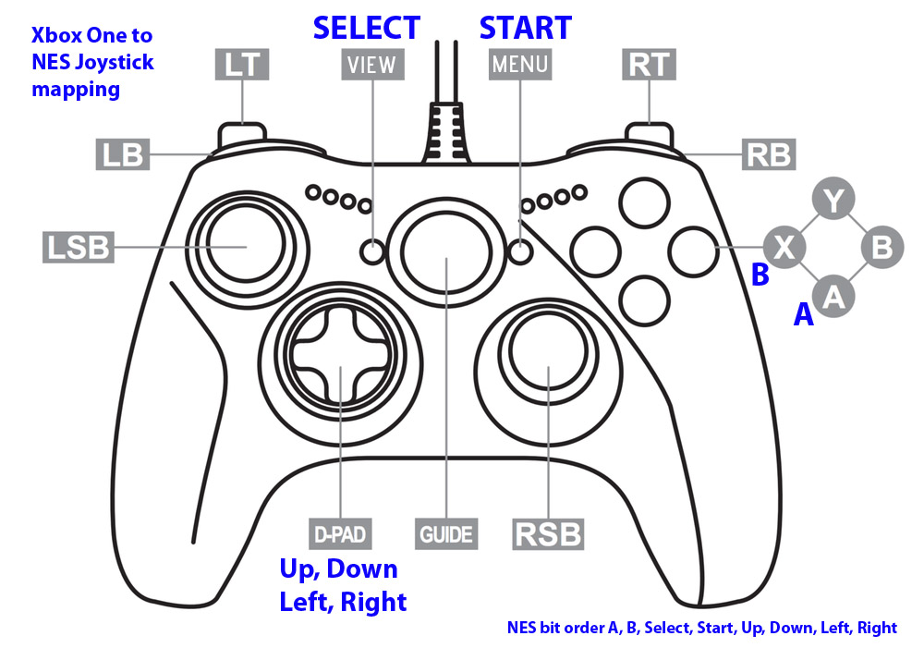
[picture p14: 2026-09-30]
doc/XBox One Controller to NES Joystick mapping.jpg

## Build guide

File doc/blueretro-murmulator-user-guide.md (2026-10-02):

# BlueRetro + Murmulator — руководство пользователя (Pairing / Unpairing)

**Версия документа:** 1.1 · **Дата:** 2026-10-02

Пошаговая инструкция для повседневного использования: как подключить Bluetooth-геймпад к BlueRetro на Мурмуляторе, как его отключить, как полностью забыть пару (не проверено) и какие геймпады совместимы. Вся техническая часть проекта — распиновка, электрическая схема, прошивка и сборка — вынесена в `blueretro-murmulator-project-summary.md`, здесь описано только пользовательское взаимодействие.

---

## 1. Пейринг Bluetooth-геймпада (проверено, Xbox One)

**Совместимость контроллера:** сопрягаются по Bluetooth только модели Xbox One геймпада с кнопкой **Sync** (чёрная круглая кнопка сверху, рядом с портом USB) — обычно модель **1708** и новее ("controller S"). Более старая модель **1537** работает только по проприетарному Xbox Wireless (без Bluetooth) и с BlueRetro не спарится.

**Режим Inquiry (поиска) — поведение по умолчанию (Auto):** если ни один контроллер не подключён, BlueRetro **автоматически** входит в режим поиска (inquiry) сразу при включении питания — нажимать кнопку BOOT/IO0 для первого пейринга **не требуется**.

Кнопка BOOT/IO0 (удержание 3–6 сек) нужна только в следующих случаях:
- пейринг уже завершился/отключился по таймауту, а нужно включить его заново;
- нужно допарить **второй** контроллер, когда первый уже подключён (у первого порта пейринг после успешного коннекта отключается);
- в BLE Web Config режим Inquiry переключён с **Auto** на **Manual** — тогда автовход в пейринг при старте отключается, и включать его нужно вручную каждый раз той же кнопкой.

**Порядок пейринга (первое подключение, режим Auto — по умолчанию):**

1. **Убедиться, что BlueRetro в режиме поиска:**
   - Включить питание BlueRetro — при отсутствии подключённых контроллеров он сам уйдёт в inquiry mode.
   - В этом состоянии **пульсируют два светодиода**: глобальный LED (IO17) и LED первого свободного порта (порт 1, IO2) — это подтверждение активного поиска. Второй порт (IO4) при этом выключен.
   - Если ни один LED не пульсирует (например, включён Manual-режим или пейринг уже был отменён) — удержать BOOT/IO0 **3–6 секунд**, чтобы включить поиск вручную.
2. **Перевести геймпад Xbox One в режим пейринга:**
   - Включить геймпад кнопкой **Xbox** (в центре).
   - Зажать чёрную кнопку **Sync** и держать, пока логотип Xbox на геймпаде не начнёт мигать.
3. **Завершение сопряжения:**
   - Логотип на геймпаде перестаёт мигать — сопряжение завершено.
   - Глобальный LED (IO17) **гаснет**, а LED занятого порта (порт 1, IO2) переходит из пульсации в **постоянное свечение (solid)** — это и есть индикация успешного подключения к конкретному порту.
4. **Инициализация стика:** нажать кнопку **A** несколько раз — нужно для корректной калибровки центрального значения аналогового стика.
5. **Повторные подключения:** заново пейрить не требуется — короткое нажатие кнопки Xbox на геймпаде переподключает его к BlueRetro автоматически.

**Второй геймпад:** после подключения первого контроллера глобальный LED (IO17) погашен, поэтому для второго геймпада нужно вручную включить поиск (удержание BOOT/IO0 3–6 сек, см. выше) — тогда LED порта 2 (IO4) начнёт пульсировать и по завершении пейринга также перейдёт в постоянное свечение.

**Настройка через Web Config:** после пейринга в BLE Web Config (blueretro.io либо локальный конфиг) убедиться, что output config нужного порта (#1 или #2) выставлен в режим **GamePad** (не Dual/Four Score).

**Соответствие битов DATA ↔ кнопки Xbox One подтверждено осциллографом** — см. раздел «Проверка сигналов осциллографом» в `blueretro-murmulator-project-summary.md` (A→A, X→B, View→Select, Menu→Start, D-pad→Up/Down/Left/Right).

---

## 2. Отключение / удаление пары (Unpairing)

Два разных сценария — просто отключить геймпад сейчас, или полностью забыть его (удалить ключ сопряжения).

### 2.1. Быстрое отключение (disconnect, без удаления пары)

Короткое нажатие кнопки BOOT/IO0 **вне режима inquiry** — отключает все Bluetooth-устройства от адаптера.

⚠️ Это разрыв текущего соединения, а не удаление ключа сопряжения — геймпад остаётся в памяти BlueRetro и при следующем включении сможет переподключиться автоматически (просто нажатием кнопки Xbox), без повторного пейринга.

**После отключения геймпада** LED освободившегося порта гаснет, а адаптер сам возвращается в режим поиска на этом порту: глобальный LED (IO17) и LED освободившегося порта снова начинают пульсировать одновременно — так же, как при первом включении.

### 2.2. Полное удаление ключей сопряжения (настоящий unpair, не проверено)

Нужно, если геймпад больше не будет использоваться с этим адаптером, или чтобы освободить слот (всего доступно до 16 ключей classic BT и 16 ключей BLE).

**Через кнопку BOOT/IO0** — удержание **6–10 секунд** (LED быстро мигает):
- Сбрасывает конфигурацию к дефолтной **и очищает все сохранённые ключи BT-пейринга**.

**Через Web Config:** на странице **System manager** (https://blueretro.io/) доступна функция **Factory Reset**, которая также стирает сохранённые пары.

⚠️ **Важно:** оба способа сбрасывают **все** сохранённые пары контроллеров сразу — точечного удаления одного конкретного устройства из списка BlueRetro не предусмотрено.

### 2.3. Сводная таблица по кнопке BOOT/IO0

| Действие | Длительность нажатия | Результат |
|---|---|---|
| Обычный сброс | < 3 сек | Reset системы |
| Вход в режим пейринга | 3–6 сек (LED мигает медленно) | Запуск inquiry mode |
| Сброс конфигурации + очистка ключей пейринга | 6–10 сек (LED мигает быстро) | Configuration reset + unpair всех устройств |
| Factory reset ESP32 | > 30 сек | Полный сброс прошивки и настроек |
| Короткое нажатие в режиме пейринга | — | Остановить пейринг / отключить все BT-устройства |

---

## 3. Совместимость геймпадов

Проверено на прошивке `v25.04 hw1 nes`.

| Геймпад | Протокол | Результат |
|---|---|---|
| Xbox One (модель 1708 и новее, с кнопкой Sync) | Classic BT | Работает (подтверждено) — см. раздел 1 |
| No-name GamePadPlus V3 (AliExpress), режим **X + Home** | BLE | Работает (подтверждено) |
| No-name GamePadPlus V3, остальные режимы (A / B / Y + Home) | BLE / Classic BT | Подключается, но кнопки не передаются (подтверждено) |

### 3.1. No-name геймпад GamePadPlus V3

Геймпад имеет четыре режима подключения, которые выбираются комбинацией кнопок при включении. С BlueRetro работает **только режим X + Home**.

**Подключение (первый раз):**

1. Убедиться, что BlueRetro в режиме поиска (пульсируют IO17 и LED свободного порта — см. раздел 1).
2. На **выключенном** геймпаде зажать кнопку **X** и, не отпуская её, нажать **Home** (центральная кнопка).
3. Геймпад сопрягается с BlueRetro: глобальный LED (IO17) гаснет, LED порта переходит в постоянное свечение.

**Повторные подключения:** геймпад запоминает последний выбранный режим — достаточно нажать **Home** (подтверждено).

**Если геймпад подключился, но кнопки не работают** (LED порта горит постоянно, но на линии DATA нет сигнала): геймпад включён в другом режиме — чаще всего в заводском A + Home. Выключить геймпад и включить заново комбинацией **X + Home**.

Каждый режим виден BlueRetro как отдельное устройство (со своим Bluetooth-адресом), поэтому после смены режима геймпад сопрягается заново и занимает отдельный ключ пейринга.

**Режимы геймпада и причины несовместимости** (по логу ESP32, см. раздел 4):

| Комбинация | Протокол | Выдаёт себя за (VID:PID) | Результат с BlueRetro |
|---|---|---|---|
| A + Home (заводской) | BLE | `1949:0402` | HID-дескриптор не разбирается (`Unknown HID marker: 36`) — нет данных |
| B + Home | Classic BT | Sony DualShock 4 `054C:09CC` | Включается драйвер PlayStation, клон не отвечает как настоящий DS4 — нет данных |
| **X + Home** | BLE | `5803:BDF8` (обычный HID-геймпад) | **Работает** |
| Y + Home | BLE | `1603:FCF1` (HID-мышь) | Режим мыши: стиков и кнопок геймпада нет — к NES неприменим |

**Признак рабочего режима в логе:** после подключения появляется строка раскладки входного отчёта, например:

```
4 I 0130 0 8 0131 8 8 0132 16 8 0135 24 8 0139 32 4 0901 40 16 02C4 56 8 02C5 64 8 rtype: 2
```

Если вместо неё стоит `Unknown HID marker` или строка содержит только кнопки и оси X/Y мыши — режим не подходит.

---

## 4. Получение лога подключения с ESP32

Лог BlueRetro в последовательном порту показывает, как геймпад подключается и распознаётся. По нему можно понять, почему подключённый геймпад не передаёт кнопки (см. раздел 3.1).

1. **Подключиться к Serial Terminal.** Подключить ESP32 к компьютеру по USB и открыть порт в SecureCRT или через `pio device monitor`. Параметры подключения (порт, скорость, настройки SecureCRT) приведены в разделе «Прошивка firmware → Serial Monitor Debug» документа `blueretro-murmulator-project-summary.md`.
2. **Перезапустить ESP32** кнопкой RESET (SW2), чтобы лог начался с момента старта.
3. **Подключить геймпад** — включить его и при необходимости выполнить пейринг (раздел 1 или 3.1).
4. **Смотреть лог в окне терминала.** Подключение, разбор геймпада и отключение выводятся построчно. Чтобы сохранить лог для анализа, скопировать вывод терминала в текстовый файл.

⚠️ Нечитаемые символы в начале вывода, сразу после старта (пока инициализируется Bluetooth-радио), — нормальное поведение, а не ошибка прошивки.

**На что смотреть в логе:**

| Строка в логе | Значение |
|---|---|
| `LE ADV ... bdaddr: ...` | Геймпад подключается по BLE |
| `Page ...` / `Inquiry ... bdaddr: ...` | Геймпад подключается по Classic BT |
| `dev: 0 type: ... <имя>` | Имя, которое сообщает геймпад |
| `VID: 0x.... PID: 0x....` | Идентификатор, под который маскируется геймпад |
| `1 I 0130 0 16 0131 16 16 ...` | Раскладка входного отчёта построена — кнопки будут передаваться |
| `Unknown HID marker: ..` | BlueRetro не смог разобрать описание геймпада — кнопки передаваться не будут |
| `DISCONN from dev: 0` | Геймпад отключился |

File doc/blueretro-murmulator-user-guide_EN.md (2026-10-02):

# BlueRetro + Murmulator — User Guide (Pairing / Unpairing)

**Document version:** 1.1 · **Date:** 2026-10-02

A step-by-step guide for everyday use: how to connect a Bluetooth gamepad to BlueRetro on the Murmulator, how to disconnect it, how to fully forget a pairing (unverified), and which gamepads are compatible. All the technical parts of the project — pinout, electrical schematic, firmware, and build — are covered in `blueretro-murmulator-project-summary_EN.md`; this document covers only the user-facing interaction.

---

## 1. Pairing a Bluetooth gamepad (verified, Xbox One)

**Controller compatibility:** only Xbox One gamepad models with a **Sync** button (the black round button on top, next to the USB port) can pair via Bluetooth — typically model **1708** and newer ("Controller S"). The older model **1537** only works over proprietary Xbox Wireless (no Bluetooth) and will not pair with BlueRetro.

**Inquiry (search) mode — default behavior (Auto):** if no controller is connected, BlueRetro **automatically** enters inquiry mode as soon as it powers on — pressing the BOOT/IO0 button for the first pairing is **not required**.

The BOOT/IO0 button (held 3–6 sec) is only needed in the following cases:
- pairing has already finished/timed out and needs to be re-enabled;
- a **second** controller needs to be paired while the first is already connected (pairing on the first port turns off after a successful connection);
- Inquiry mode has been switched from **Auto** to **Manual** in BLE Web Config — in that case auto-entry into pairing at startup is disabled, and it must be enabled manually each time with the same button.

**Pairing procedure (first connection, Auto mode — default):**

1. **Make sure BlueRetro is in search mode:**
   - Power on BlueRetro — with no controllers connected, it enters inquiry mode by itself.
   - In this state **two LEDs pulse**: the global LED (IO17) and the LED of the first free port (port 1, IO2) — this confirms that the search is active. The second port (IO4) is off.
   - If no LED is pulsing (for example, Manual mode is enabled or pairing was already cancelled), hold BOOT/IO0 for **3–6 seconds** to start the search manually.
2. **Put the Xbox One gamepad into pairing mode:**
   - Turn the gamepad on with the **Xbox** button (in the center).
   - Press and hold the black **Sync** button until the Xbox logo on the gamepad starts blinking.
3. **Completing the pairing:**
   - The logo on the gamepad stops blinking — pairing is complete.
   - The global LED (IO17) **turns off**, and the LED of the occupied port (port 1, IO2) changes from pulsing to **steady (solid)** — this indicates a successful connection to that specific port.
4. **Stick initialization:** press the **A** button several times — this is needed to calibrate the center value of the analog stick correctly.
5. **Reconnecting:** no need to pair again — a short press of the Xbox button on the gamepad reconnects it to BlueRetro automatically.

**Second gamepad:** after the first controller connects, the global LED (IO17) is off, so for the second gamepad the search must be enabled manually (hold BOOT/IO0 for 3–6 sec, see above) — the port 2 LED (IO4) then starts pulsing and, once pairing completes, also changes to steady.

**Web Config setup:** after pairing, check in BLE Web Config (blueretro.io or the local config) that the output config of the relevant port (#1 or #2) is set to **GamePad** mode (not Dual/Four Score).

**The DATA bit ↔ Xbox One button mapping is confirmed with an oscilloscope** — see the "Oscilloscope signal verification" section in `blueretro-murmulator-project-summary_EN.md` (A→A, X→B, View→Select, Menu→Start, D-pad→Up/Down/Left/Right).

---

## 2. Disconnecting / removing a pairing (Unpairing)

Two different scenarios — just disconnect the gamepad now, or forget it completely (delete the pairing key).

### 2.1. Quick disconnect (without removing the pairing)

A short press of the BOOT/IO0 button **outside of inquiry mode** disconnects all Bluetooth devices from the adapter.

⚠️ This breaks the current connection but does not delete the pairing key — the gamepad stays in BlueRetro's memory and can reconnect automatically next time (just by pressing the Xbox button), without pairing again.

**After the gamepad disconnects**, the LED of the freed port turns off, and the adapter returns to search mode on that port by itself: the global LED (IO17) and the LED of the freed port start pulsing together again — just like at first power-on.

### 2.2. Fully deleting pairing keys (true unpair, unverified)

Needed if the gamepad will no longer be used with this adapter, or to free a slot (up to 16 classic BT keys and 16 BLE keys are available in total).

**Via the BOOT/IO0 button** — hold for **6–10 seconds** (LED blinks fast):
- Resets the configuration to default **and clears all stored BT pairing keys**.

**Via Web Config:** the **System manager** page (https://blueretro.io/) offers a **Factory Reset** function, which also erases the stored pairings.

⚠️ **Important:** both methods reset **all** stored controller pairings at once — BlueRetro does not support removing one specific device from the list.

### 2.3. BOOT/IO0 button summary

| Action | Press duration | Result |
|---|---|---|
| Normal reset | < 3 sec | System reset |
| Enter pairing mode | 3–6 sec (LED blinks slowly) | Starts inquiry mode |
| Configuration reset + clear pairing keys | 6–10 sec (LED blinks fast) | Configuration reset + unpair all devices |
| ESP32 factory reset | > 30 sec | Full firmware and settings reset |
| Short press in pairing mode | — | Stop pairing / disconnect all BT devices |

---

## 3. Gamepad compatibility

Verified on firmware `v25.04 hw1 nes`.

| Gamepad | Protocol | Result |
|---|---|---|
| Xbox One (model 1708 and newer, with the Sync button) | Classic BT | Works (confirmed) — see section 1 |
| No-name GamePadPlus V3 (AliExpress), **X + Home** mode | BLE | Works (confirmed) |
| No-name GamePadPlus V3, other modes (A / B / Y + Home) | BLE / Classic BT | Connects, but buttons are not transmitted (confirmed) |

### 3.1. No-name GamePadPlus V3 gamepad

The gamepad has four connection modes, selected by a button combination at power-on. **Only the X + Home mode** works with BlueRetro.

**Connecting (first time):**

1. Make sure BlueRetro is in search mode (IO17 and the free port LED are pulsing — see section 1).
2. With the gamepad **turned off**, press and hold the **X** button and, without releasing it, press **Home** (the center button).
3. The gamepad pairs with BlueRetro: the global LED (IO17) turns off, and the port LED changes to steady.

**Reconnecting:** the gamepad remembers the last selected mode — just press **Home** (confirmed).

**If the gamepad has connected but the buttons do not work** (the port LED is steady, but there is no signal on the DATA line): the gamepad is in a different mode — most often the factory A + Home mode. Turn the gamepad off and turn it on again with the **X + Home** combination.

BlueRetro sees each mode as a separate device (with its own Bluetooth address), so after a mode change the gamepad pairs again and occupies a separate pairing key.

**Gamepad modes and reasons for incompatibility** (from the ESP32 log, see section 4):

| Combination | Protocol | Identifies itself as (VID:PID) | Result with BlueRetro |
|---|---|---|---|
| A + Home (factory) | BLE | `1949:0402` | HID descriptor is not parsed (`Unknown HID marker: 36`) — no data |
| B + Home | Classic BT | Sony DualShock 4 `054C:09CC` | The PlayStation driver is enabled, the clone does not respond like a real DS4 — no data |
| **X + Home** | BLE | `5803:BDF8` (generic HID gamepad) | **Works** |
| Y + Home | BLE | `1603:FCF1` (HID mouse) | Mouse mode: no gamepad sticks or buttons — not applicable to NES |

**Sign of a working mode in the log:** after connecting, an input report layout line appears, for example:

```
4 I 0130 0 8 0131 8 8 0132 16 8 0135 24 8 0139 32 4 0901 40 16 02C4 56 8 02C5 64 8 rtype: 2
```

If instead there is `Unknown HID marker`, or the line contains only mouse buttons and X/Y axes, the mode is not suitable.

---

## 4. Getting the connection log from the ESP32

The BlueRetro serial port log shows how the gamepad connects and is recognized. It can be used to find out why a connected gamepad does not transmit buttons (see section 3.1).

1. **Connect to the Serial Terminal.** Connect the ESP32 to the computer via USB and open the port in SecureCRT or with `pio device monitor`. The connection parameters (port, baud rate, SecureCRT settings) are given in the "Firmware → Serial Monitor Debug" section of `blueretro-murmulator-project-summary_EN.md`.
2. **Restart the ESP32** with the RESET button (SW2), so the log starts from boot.
3. **Connect the gamepad** — turn it on and pair it if needed (section 1 or 3.1).
4. **Watch the log in the terminal window.** Connection, gamepad parsing, and disconnection are printed line by line. To save the log for analysis, copy the terminal output into a text file.

⚠️ Unreadable characters at the beginning of the output, right after boot (while the Bluetooth radio initializes), are normal behavior, not a firmware fault.

**What to look for in the log:**

| Log line | Meaning |
|---|---|
| `LE ADV ... bdaddr: ...` | The gamepad connects via BLE |
| `Page ...` / `Inquiry ... bdaddr: ...` | The gamepad connects via Classic BT |
| `dev: 0 type: ... <name>` | The name reported by the gamepad |
| `VID: 0x.... PID: 0x....` | The identifier the gamepad presents itself as |
| `1 I 0130 0 16 0131 16 16 ...` | The input report layout has been built — buttons will be transmitted |
| `Unknown HID marker: ..` | BlueRetro could not parse the gamepad description — buttons will not be transmitted |
| `DISCONN from dev: 0` | The gamepad has disconnected |

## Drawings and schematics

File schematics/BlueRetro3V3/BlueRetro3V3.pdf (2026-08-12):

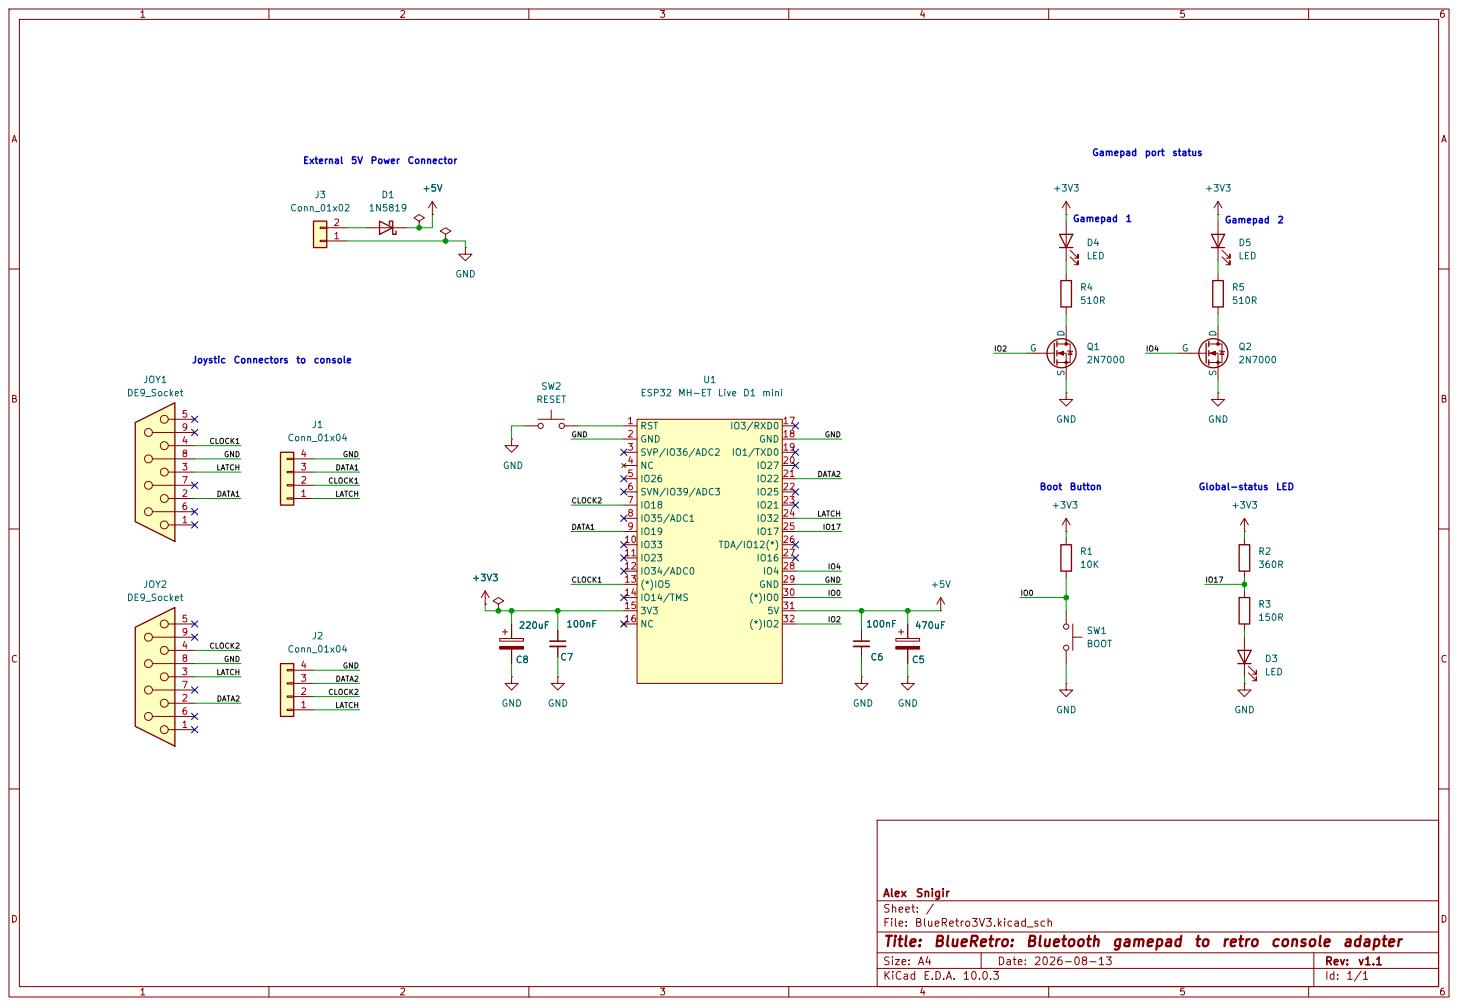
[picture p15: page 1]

ESP32 MH-ET Live D1 mini 1

Alex Snigir
Sheet: /
File: BlueRetro3V3.kicad_sch
Title: BlueRetro: Bluetooth gamepad to retro console adapter

Size: A4 | Rev: v1.1
KiCad E.D.A. 10.0.3 | Id: 1/1

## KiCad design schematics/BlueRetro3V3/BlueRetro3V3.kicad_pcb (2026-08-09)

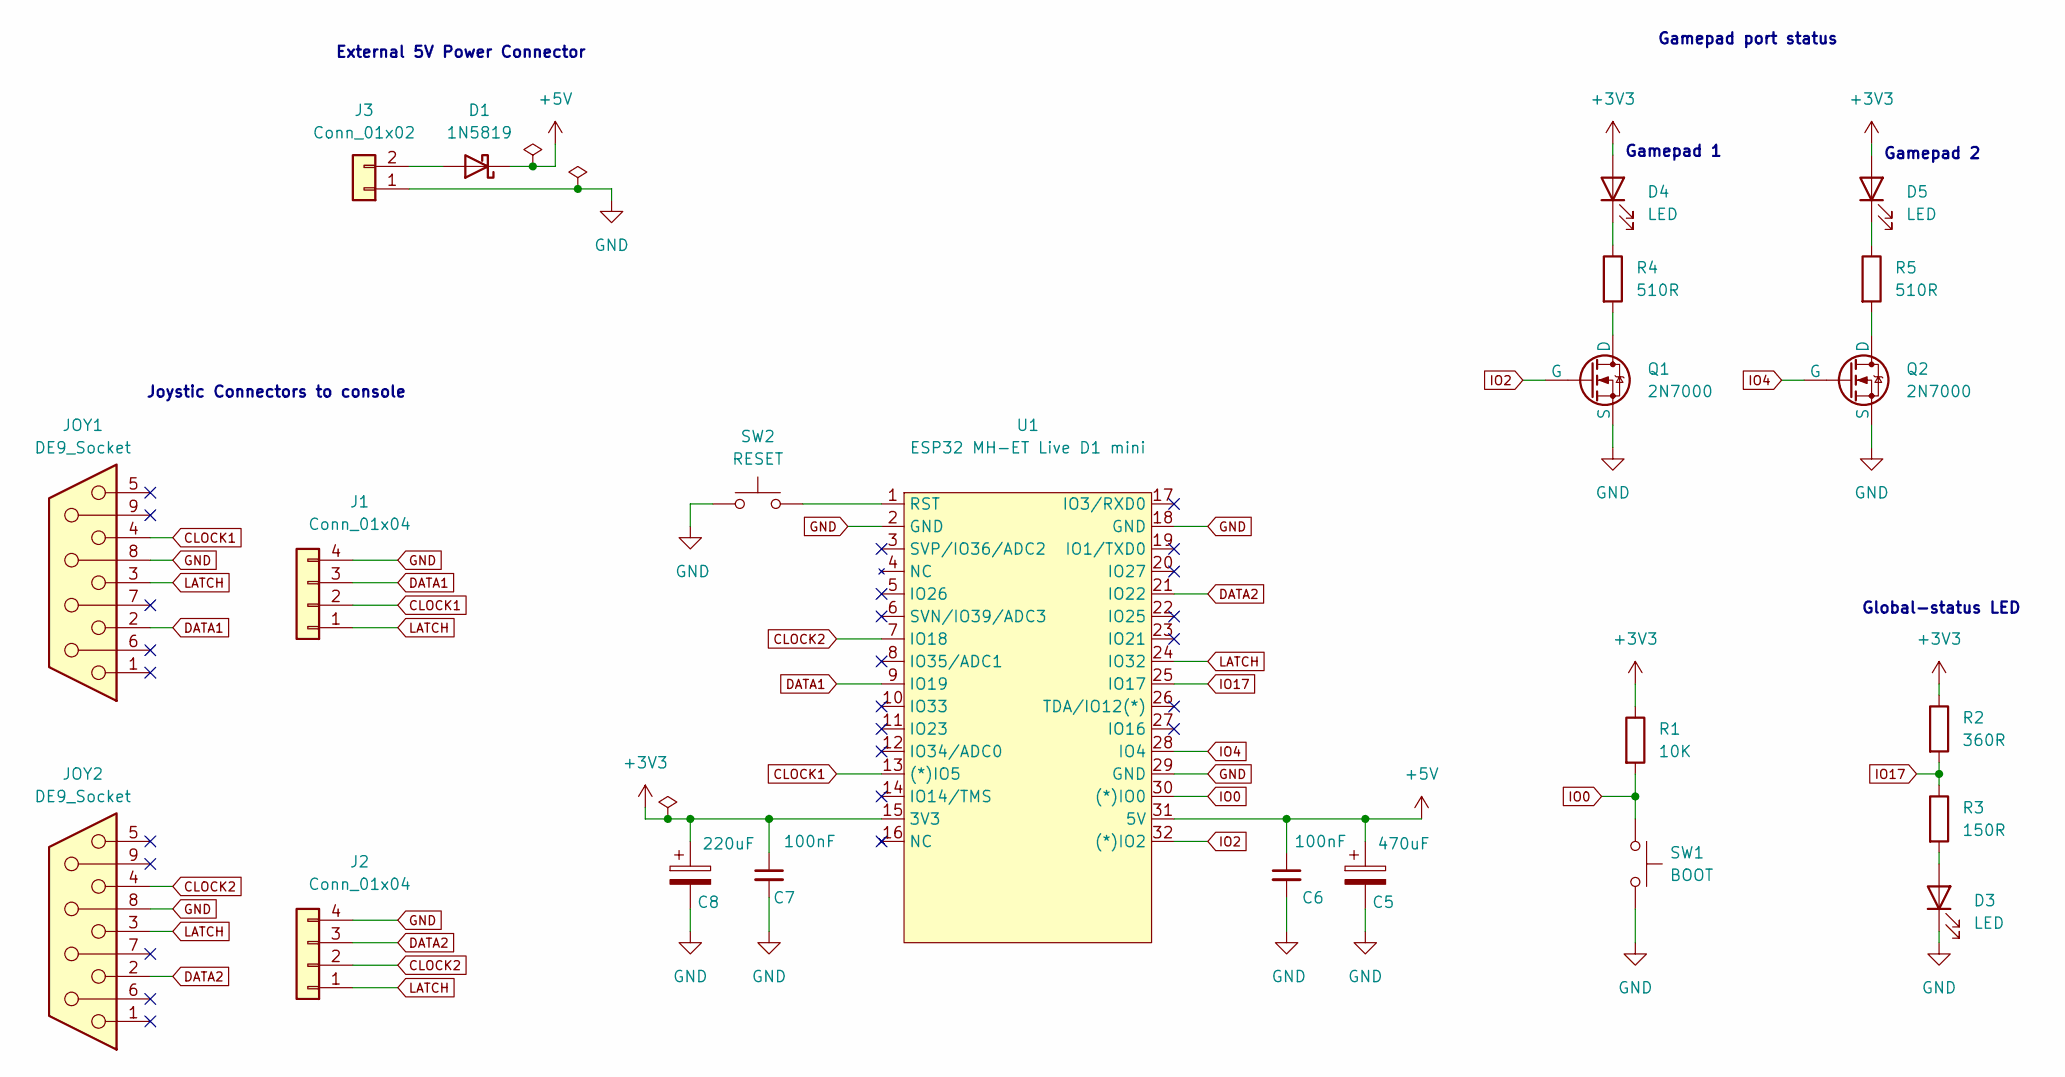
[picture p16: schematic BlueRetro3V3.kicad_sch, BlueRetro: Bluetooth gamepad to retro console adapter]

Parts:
C5: 470uF; CP_Radial_D8.0mm_P2.50mm
C6, C7: 100nF; C_Disc_D5.0mm_W2.5mm_P2.50mm
C8: 220uF; CP_Radial_D6.3mm_P2.50mm
D1: 1N5819; D_DO-41_SOD81_P7.62mm_Horizontal
D3, D4, D5: LED; LED_D5.0mm
J1, J2: Conn_01x04; JST_XH_S4B-XH-A_1x04_P2.50mm_Horizontal
J3: Conn_01x02; JST_XH_S2B-XH-A_1x02_P2.50mm_Horizontal
JOY1, JOY2: DE9_Socket
Q1, Q2: 2N7000; TO-92_Inline_Wide_2N7000
R1: 10K; R_Axial_DIN0207_L6.3mm_D2.2mm_P10.16mm_Horizontal
R2: 360R; R_Axial_DIN0207_L6.3mm_D2.2mm_P10.16mm_Horizontal
R3: 150R; R_Axial_DIN0207_L6.3mm_D2.2mm_P10.16mm_Horizontal
R4, R5: 510R; R_Axial_DIN0207_L6.3mm_D2.2mm_P10.16mm_Horizontal
SW1: BOOT; SW_Tactile_SKHH_Angled
SW2: RESET; SW_Tactile_SKHH_Angled
U1: ESP32 MH-ET Live D1 mini; ESP32_MH-ET_Live_D1_mini_32_pins

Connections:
+3V3: C7.1, C8.1, D4.2 (A), D5.2 (A), R1.1, R2.1, U1.15 (3V3)
+5V: C5.1, C6.1, D1.1 (K), U1.31 (5V)
CLOCK1: J1.2, JOY1.4, U1.13 ((*)IO5)
CLOCK2: J2.2, JOY2.4, U1.7 (IO18)
DATA1: J1.3, JOY1.2, U1.9 (IO19)
DATA2: J2.3, JOY2.2, U1.21 (IO22)
GND: C5.2, C6.2, C7.2, C8.2, D3.1 (K), J1.4, J2.4, J3.1, JOY1.8, JOY2.8, Q1.3 (S), Q2.3 (S), SW1.2, SW2.1, U1.2 (GND), U1.18 (GND), U1.29 (GND)
IO0: R1.2, SW1.1, U1.30 ((*)IO0)
IO2: Q1.2 (G), U1.32 ((*)IO2)
IO4: Q2.2 (G), U1.28 (IO4)
IO17: R2.2, R3.1, U1.25 (IO17)
LATCH: J1.1, J2.1, JOY1.3, JOY2.3, U1.24 (IO32)
unnamed: D1.2 (A), J3.2
unnamed: D3.2 (A), R3.2
unnamed: D4.1 (K), R4.1
unnamed: D5.1 (K), R5.1
unnamed: Q1.1 (D), R4.2
unnamed: Q2.1 (D), R5.2
unnamed: SW2.2, U1.1 (RST)

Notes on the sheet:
Joystic Connectors to console
Gamepad 2
Gamepad 1
External 5V Power Connector
Global-status LED
Gamepad port status

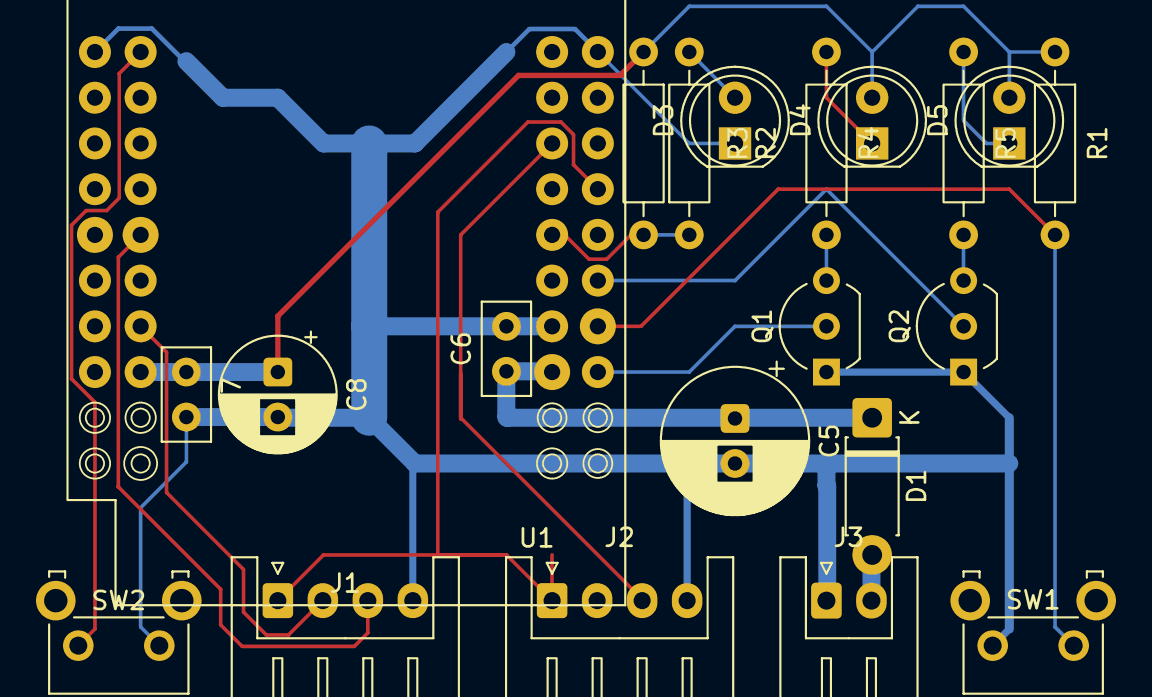
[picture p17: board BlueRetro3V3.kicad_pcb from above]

Board: 2 copper layers, 21 parts (0 on the bottom side), 19 nets.

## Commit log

2026-08-09 import files
    [BlueRetro3V3.kicad_pcb, BlueRetro3V3.kicad_sch]
2026-08-12 schematics minor update
    [BlueRetro3V3.kicad_sch]
